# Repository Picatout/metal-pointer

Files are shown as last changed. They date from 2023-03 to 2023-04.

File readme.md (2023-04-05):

# Nail metal detector 

This is a mail metal detector using a NUCLEO-8S207K8 module with [stm8_tbi](https://github.com/picatout/stm8_tbi).

The Tiny BASIC application  [metal-detector.bas](metal-detector.bas)

* [revision notes](#revisions) 

##  Final choice for circuit 

At the end I chose the **L-R** time constant variation circuit for the stability and a coil with ferrite for sensivity . See [bare-metal/readme.md](bare-metal/readme.md) for more information. 

## Schematic, version 2

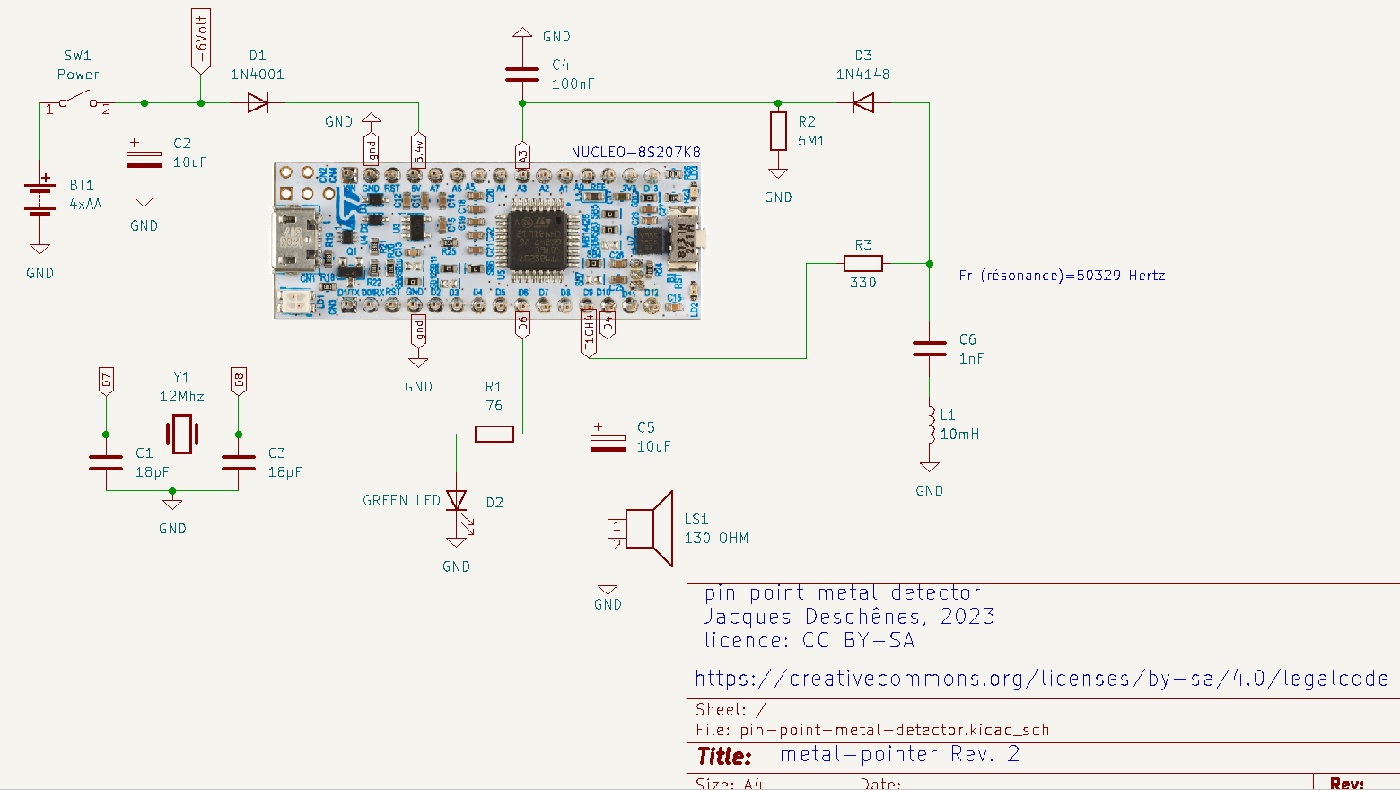
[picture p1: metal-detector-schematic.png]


## prototype, version 1



## Working principle

**C6** and **L1** form a series resonance circuit which frequency is 
Fr=1/(2 * 3.1416 * sqrt(1e-9*10e-3))=50329 Hertz 

**PWM** Channel 4 is used to generate a frequency at or near resonnance. This signal is injected in C4-L1 through R3. At resonant frequency voltage at junction R3-C4 is minimum.
This voltage is rectified by diode **D3** and measured by the analog/digital converter on channel **A3**. 

When a metal object come close to **L1** it modify the inductance then **C6-L1** resonnance is no more at PWM frequency and the voltage increase at **R3-C6** junction. An alarm is then sounded for 10msec and the GREEN LED **D2** light up. 

12Mhz crystal **Y1** is added to the NUCLEO-S207K8 board to increase frequency stability.

**L1** is a commercial inductor wound on a ferrite core. 

## Revisions 

### 2023-03-05 

Final assembly see [bare-metal/readme.md](bare-metal/readme.md)

### version 7 (STM8103F3M) final circuit 

* Final source code:  [nail-finder.v6.asm](bare-metal/nail-finder.v6.asm)

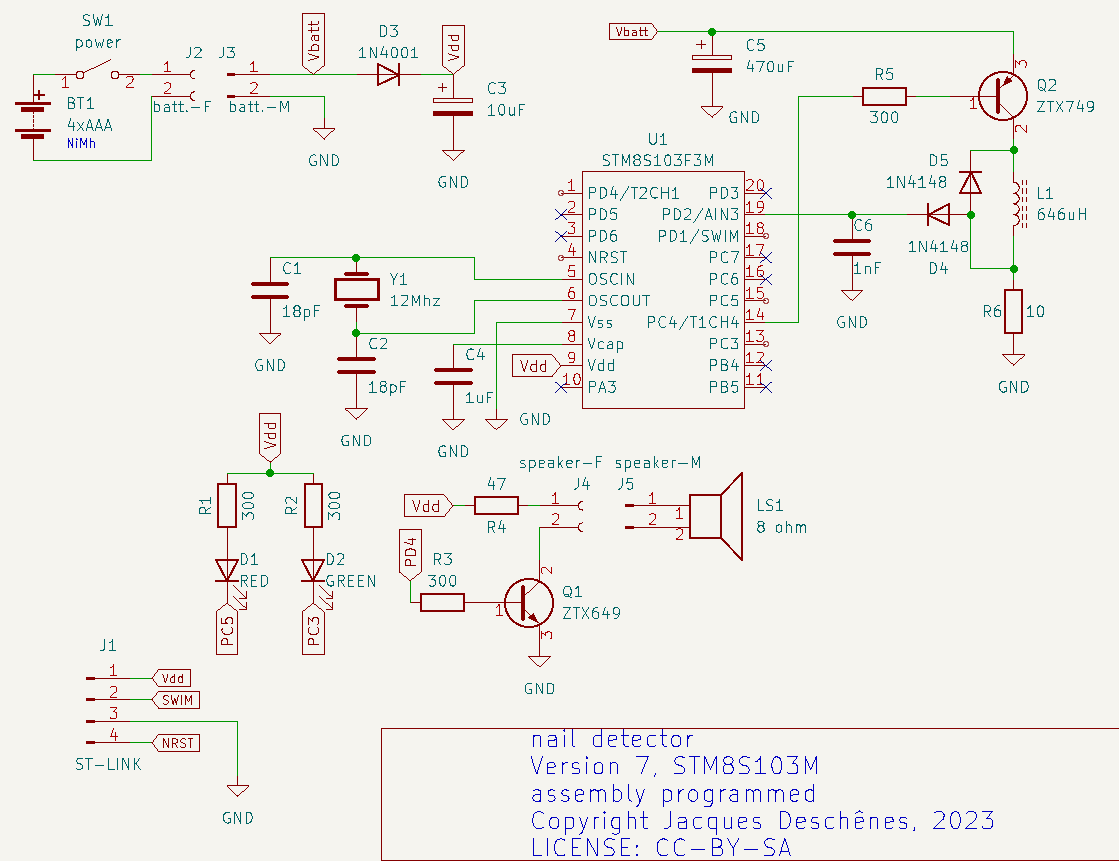
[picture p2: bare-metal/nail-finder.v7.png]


### version 6 (STM8S103F3M) assembly coded. 

Best result up to now. see [bare-metal/readme.md](bare-metal/readme.md) for detail.

### version 3 (STM8S105KBB6) R2

* Added double tonalities to alarm to distinguish between *going closer* and *going further*. For steel going closer generate higher pitch and going further generate lower pitch. For nickel it is the opposite.

* Added a buffer transistor to speaker as the sounding alarm was dropping *Vdda* affecting sample reading.

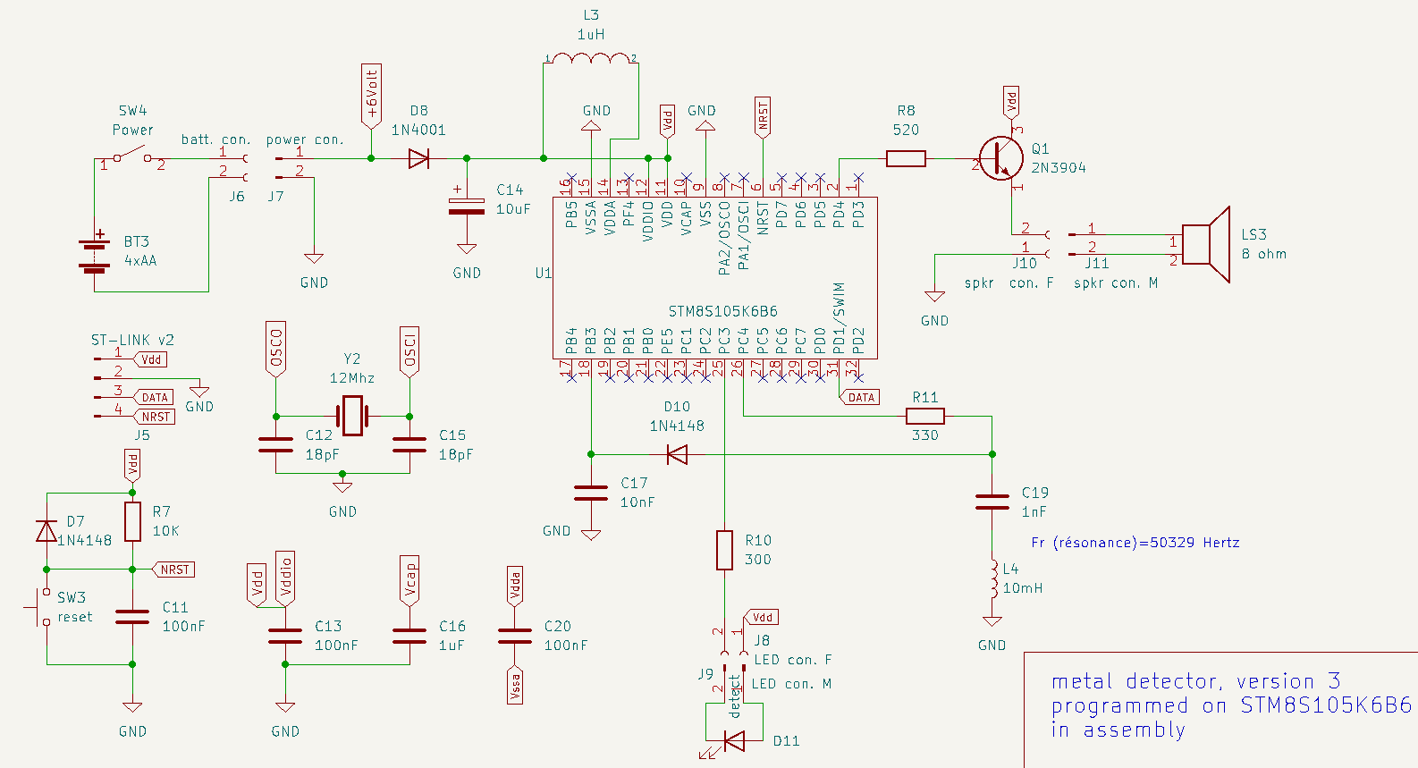
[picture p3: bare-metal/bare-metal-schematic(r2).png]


### version 3  (STM8S105KBB6) R1

Bare metal programming in assembly on STM8S105K6B6. 

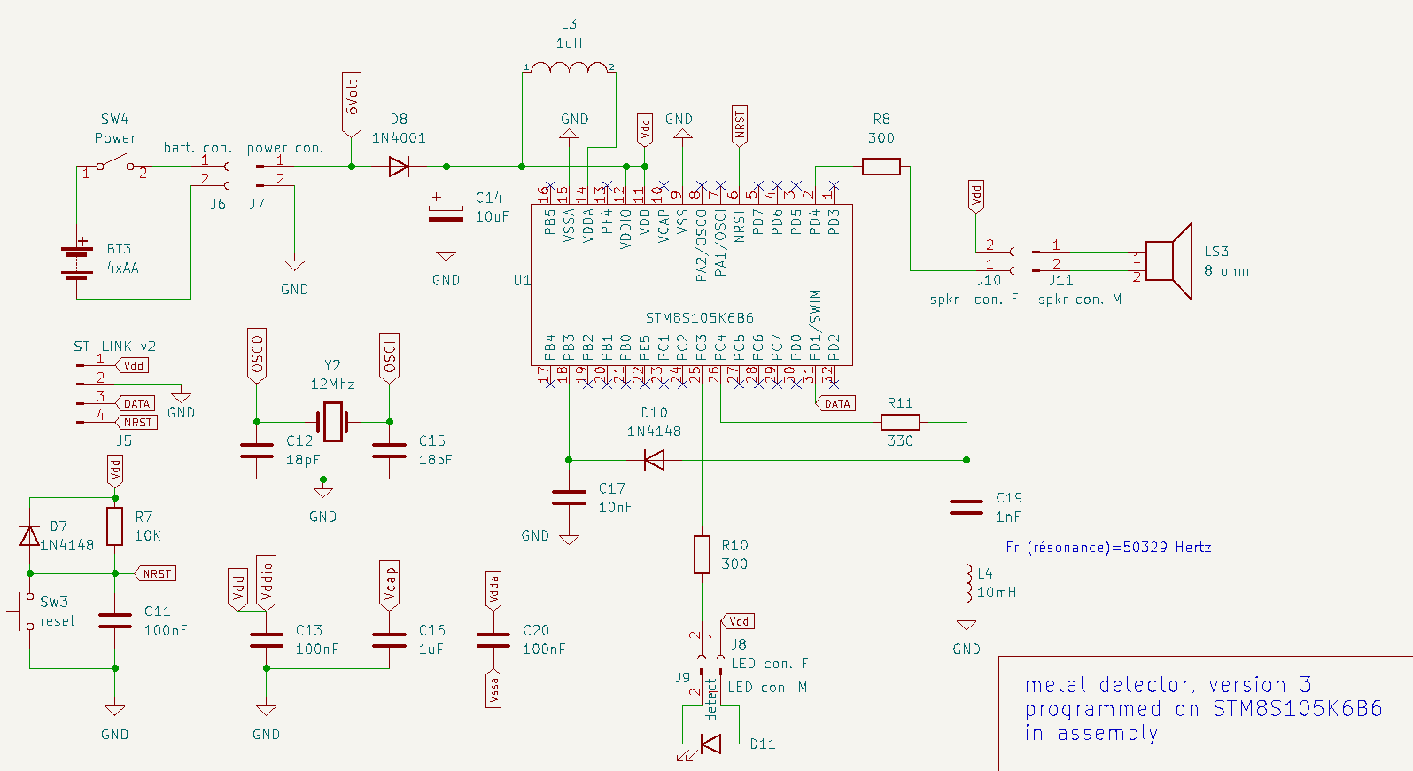
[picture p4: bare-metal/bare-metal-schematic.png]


### Version 2 

* Sheet **version 2** in KiCAD schematic. In this version the external 12Mhz crystal is discarded. The **SB5** bride on NUCLEO board is closed which bring 8Mhz **TMCO** signal to STM8 PA1 pin.
This version of metal detector use new command **CLK_HSE** from last version of [STM8 Tiny BASIC](https://github.com/picatout/stm8_tbi).

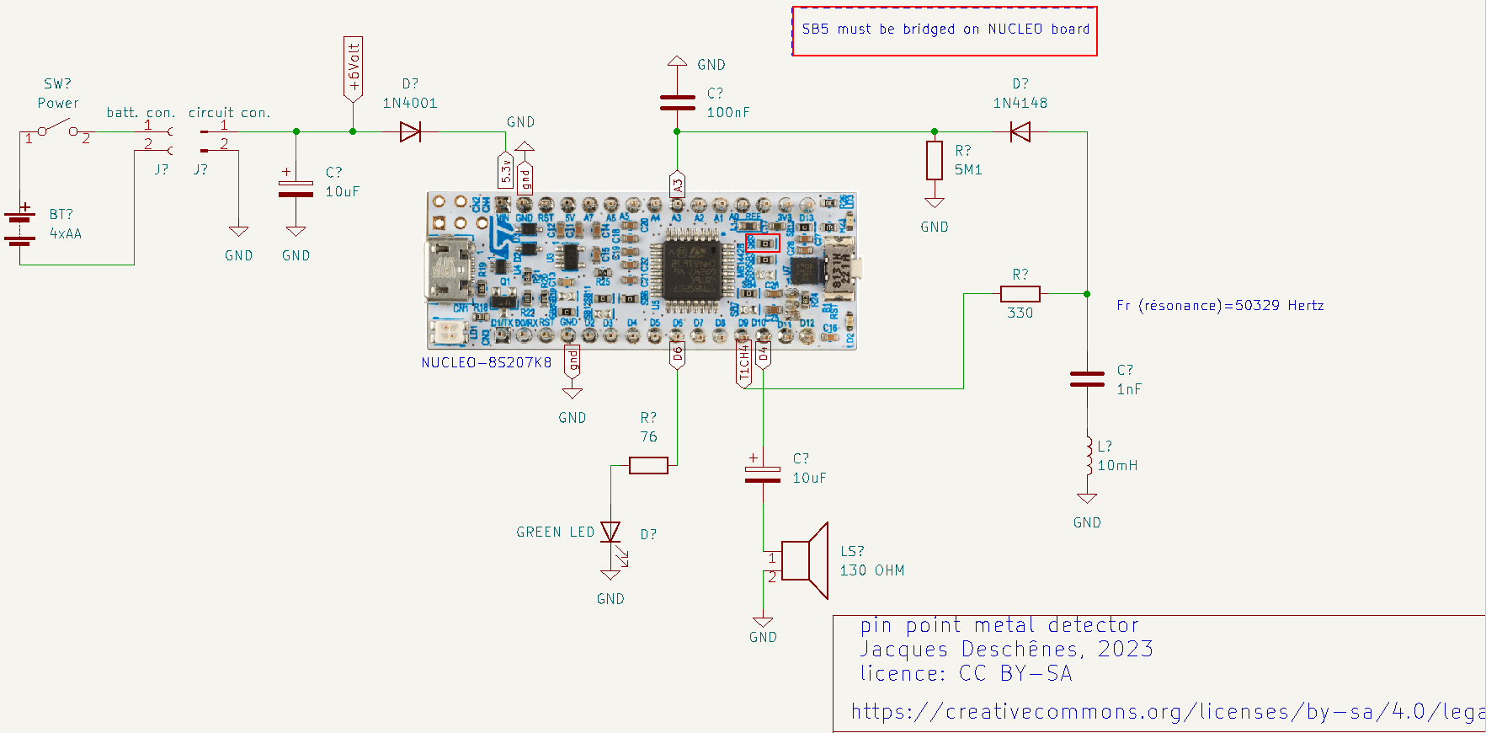
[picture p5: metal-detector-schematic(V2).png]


### Revision 3 

* I had wrongly connected cathode of **D1** to **CN4:4 (Vin)**  instead of **CN4:1 (5V)**.    

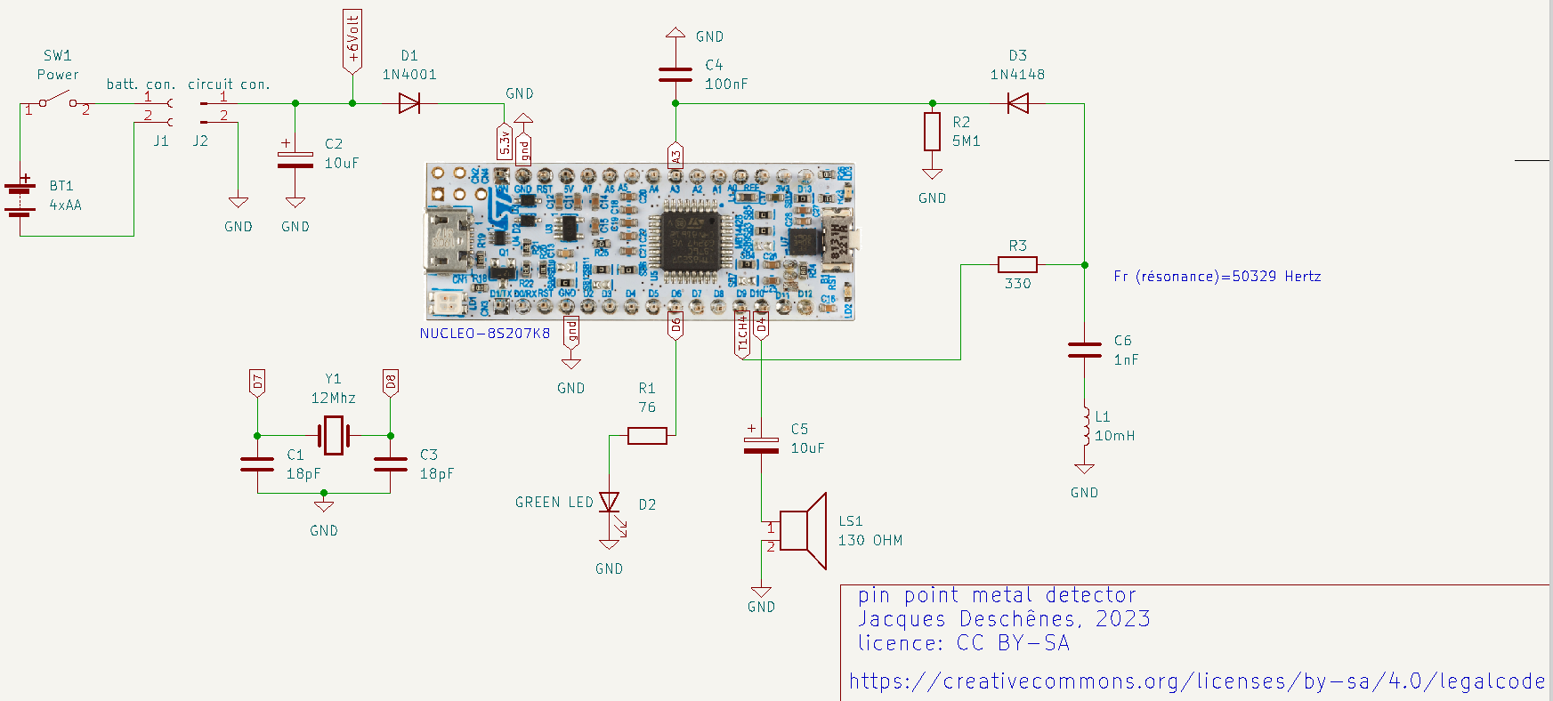
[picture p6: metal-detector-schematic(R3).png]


[short video demo](https://youtube.com/shorts/o5VKi-kE5qI?feature=share) 

### Revision 2 

*  Modified schematic and [metal-detector.bas](metal-detector.bas) to improve sensitivity.

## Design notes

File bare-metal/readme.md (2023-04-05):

# Version 7 
### 2023-04-05

Last circuit modification, new coil to increase detection area. I replaced the rod wounded coil by half cylindral wounded coil. The inductance is a little higher 646µH instead of 622µH. 
For this coil I used half of cable ferrite as core. 

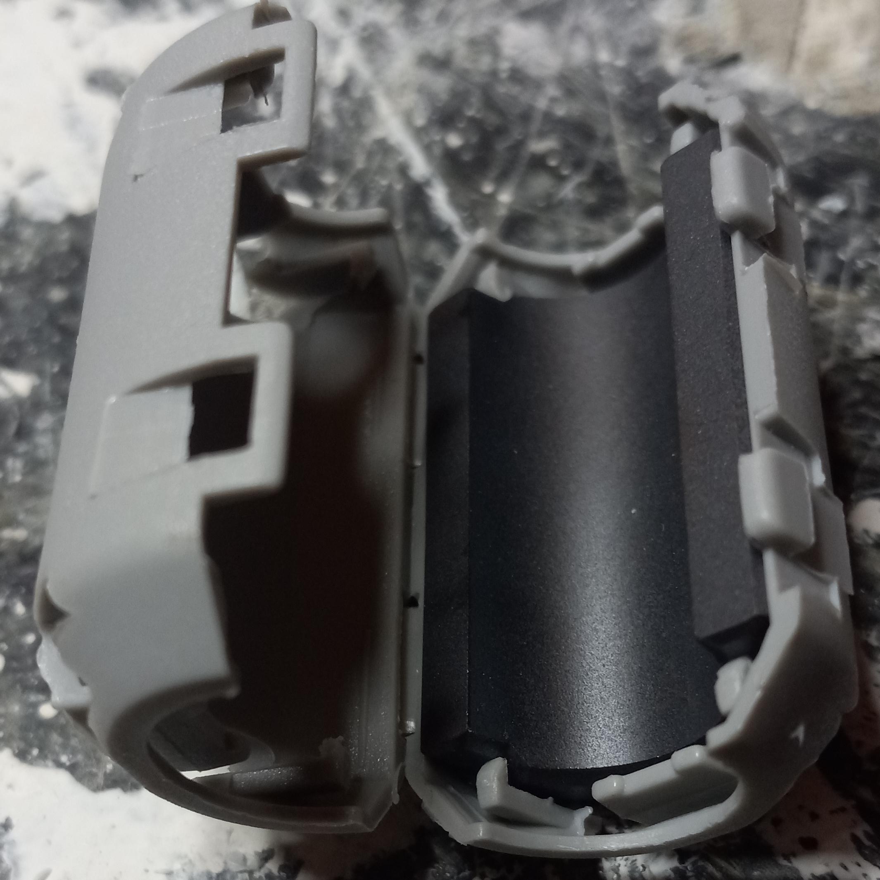
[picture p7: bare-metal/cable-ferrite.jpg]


I removed one half from plastic shell to use as core. Using 30 AWG enameled wire . With 2 layers of this wire I measured 644µH. 

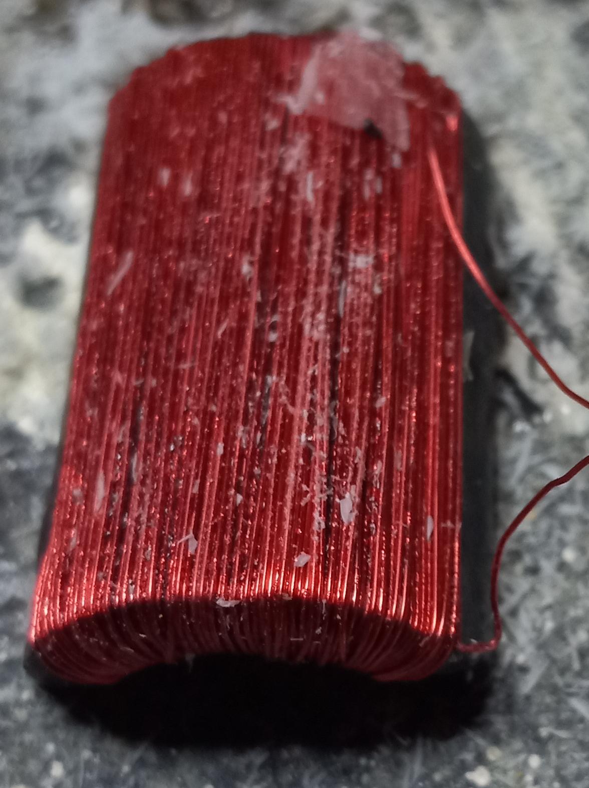
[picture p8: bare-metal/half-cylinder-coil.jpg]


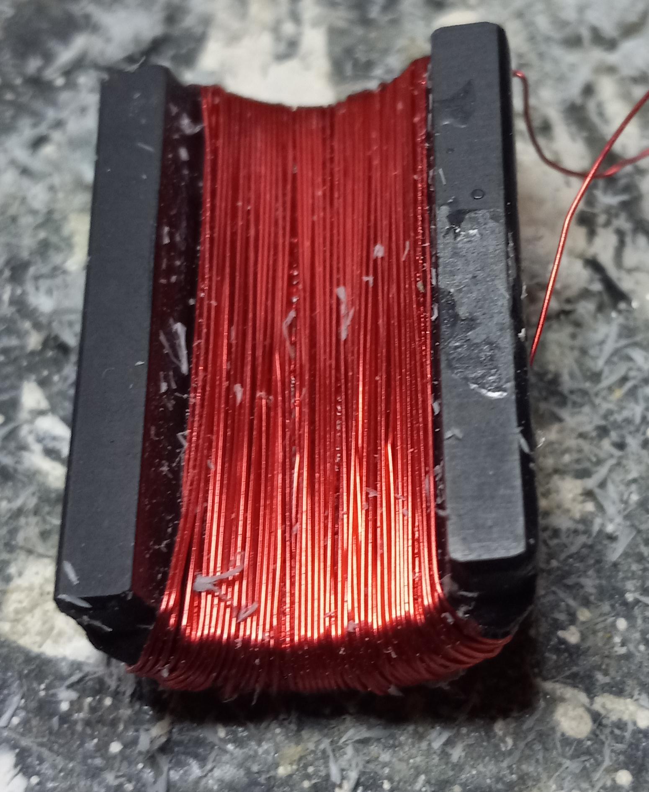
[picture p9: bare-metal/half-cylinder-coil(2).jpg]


I cutted 2 slot at the bottom of the box to push the coil edges flush to it an used epoxy glue to hold in place.

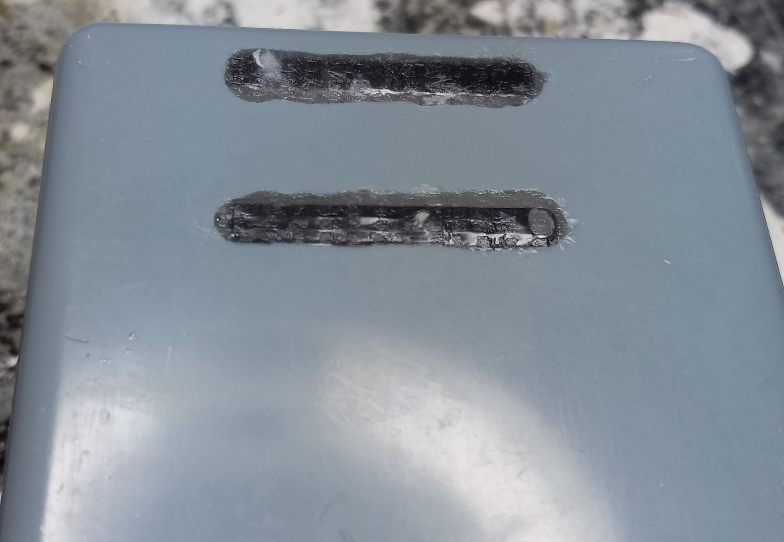
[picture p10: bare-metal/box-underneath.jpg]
box-underneath


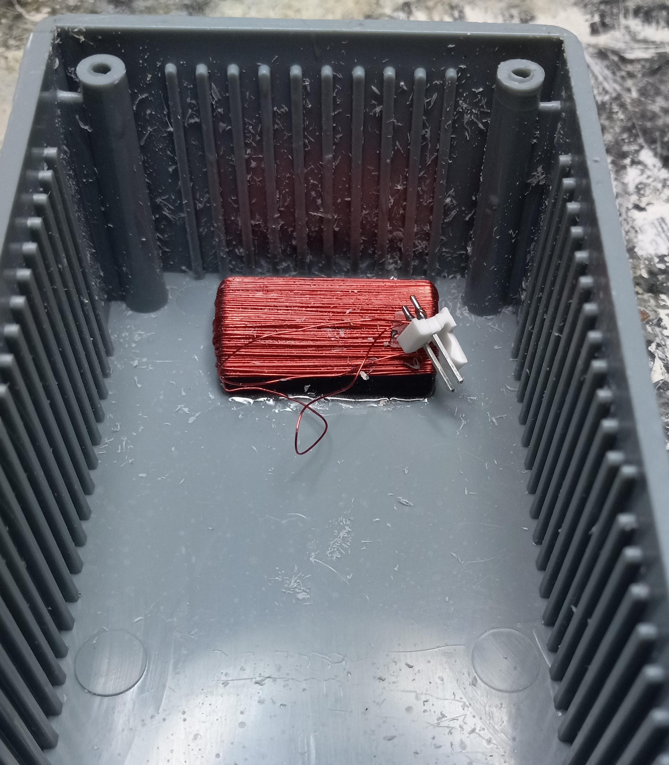
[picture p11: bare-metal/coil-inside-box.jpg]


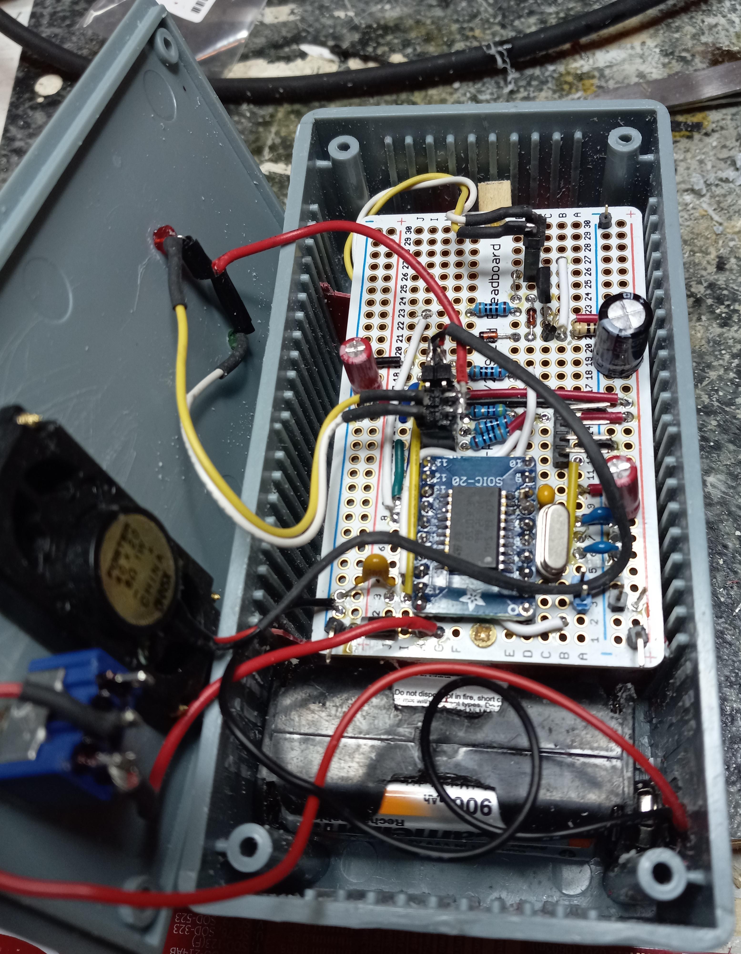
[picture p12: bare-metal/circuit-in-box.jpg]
circuit in box


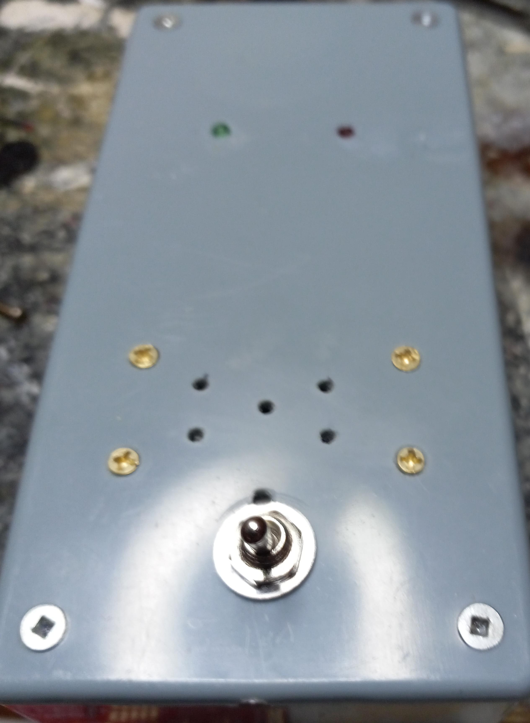
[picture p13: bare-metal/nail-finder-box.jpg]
nail finder box


Demo video [here](https://youtu.be/uCpbacAko6Q).

## 2023-03-29 

* Improved sensivity. 

* Tried a new coil on rod ferrite. [rod datasheet](ferrite-rod-4077484611.pdf).

* Updated firmware [nail-finder.v6.asm](nail-finder.v6.asm).

After many different circuits test I decided for the following circuit giving the best result.
* Use **STM8S103F3M**  SOIC-20 format  MCU. 
* Coded in assembly [nail-finder.v6.asm](nail-finder.v6.asm).



I'm waiting for an ordered ferrite to test new coil idea before doing a final assembly.

### How it works 

The working principle is different from previous version. Instead on measuring difference in voltage induced by varying resonnance frequency.  It measure variations in voltage induce by variation in time constant of **L-R** circuit.   

A short pulse is sent to **L1-R4** circuit. Voltage at **R4** increase exponentially in relation to Time constant **T=L/R**.  Metal nearby **L1** change its inductance hence the time constant variation. The duration of pulse is chosen to be short enough that the voltage at **R1** never reach Vdd (current through L1-R1 never reach its maximum). Hence the voltage at end of pulse depend on time constant.

This circuit prove to be very reliable in stability and the **L1** ferrite core improve sensitivity. 

# version 6 

* best result up to date. 
    * improved sensivity 
    * very few false alarms. 

[new software](nail-finder.v6.asm) and new circuit. 

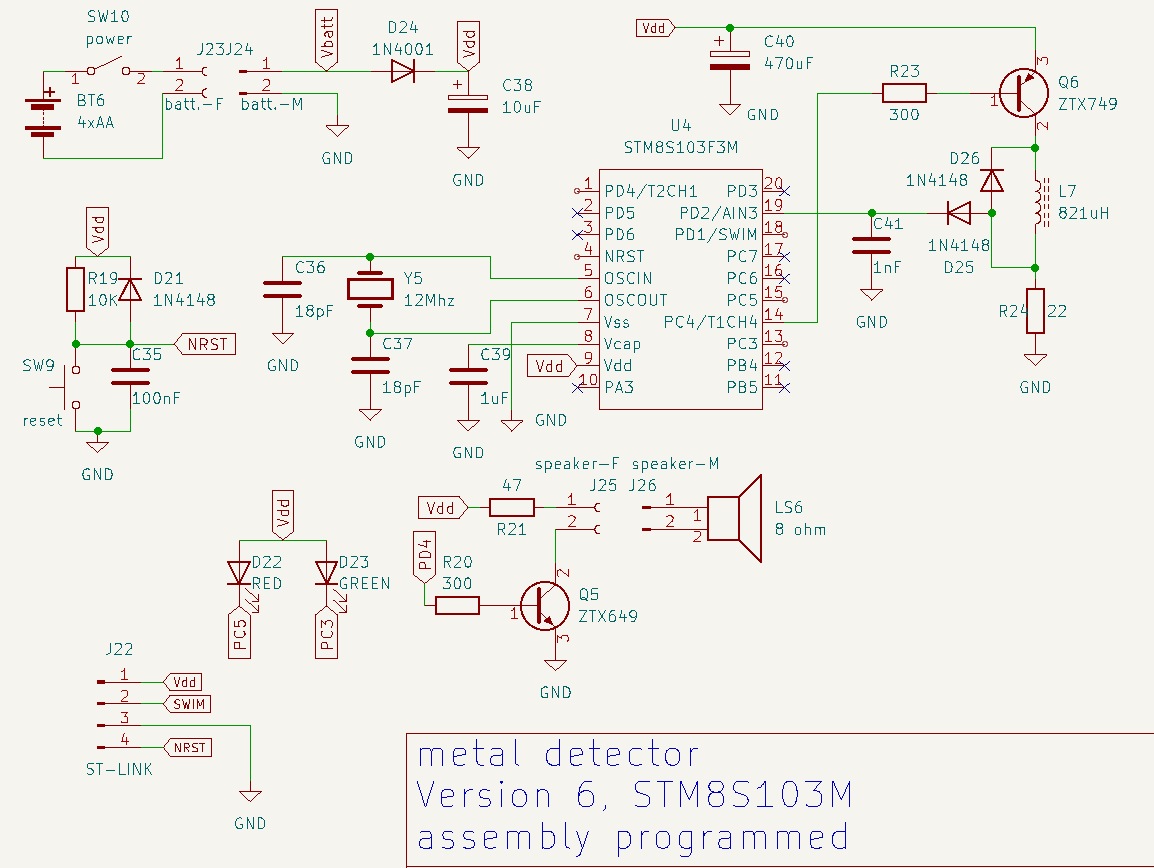
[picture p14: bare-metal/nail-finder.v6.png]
new circuit
 

The inductor **L7** is 26 AWG enamel wire wounded on a ferrite rod recuperated from old radio. 
The rod is 7mm diameter. The winding is 2 layers 3 cm in length. The measure inductance is 821uH.

# version 4 

### 2023-03-22 

La configuration tested. Use a coil on ferrite rod.

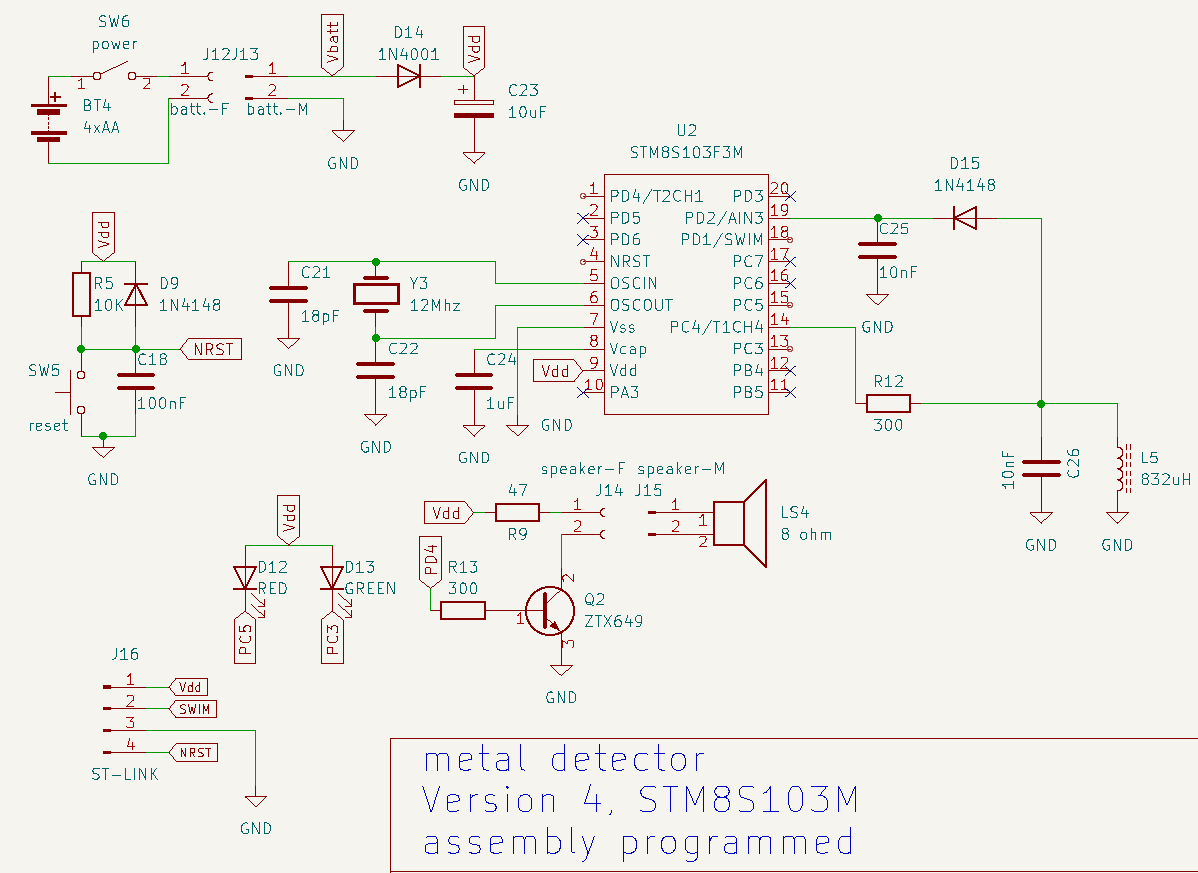
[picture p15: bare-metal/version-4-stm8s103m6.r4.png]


This version is programmed on **STM8S103F3M" in assembly. Still in development. 

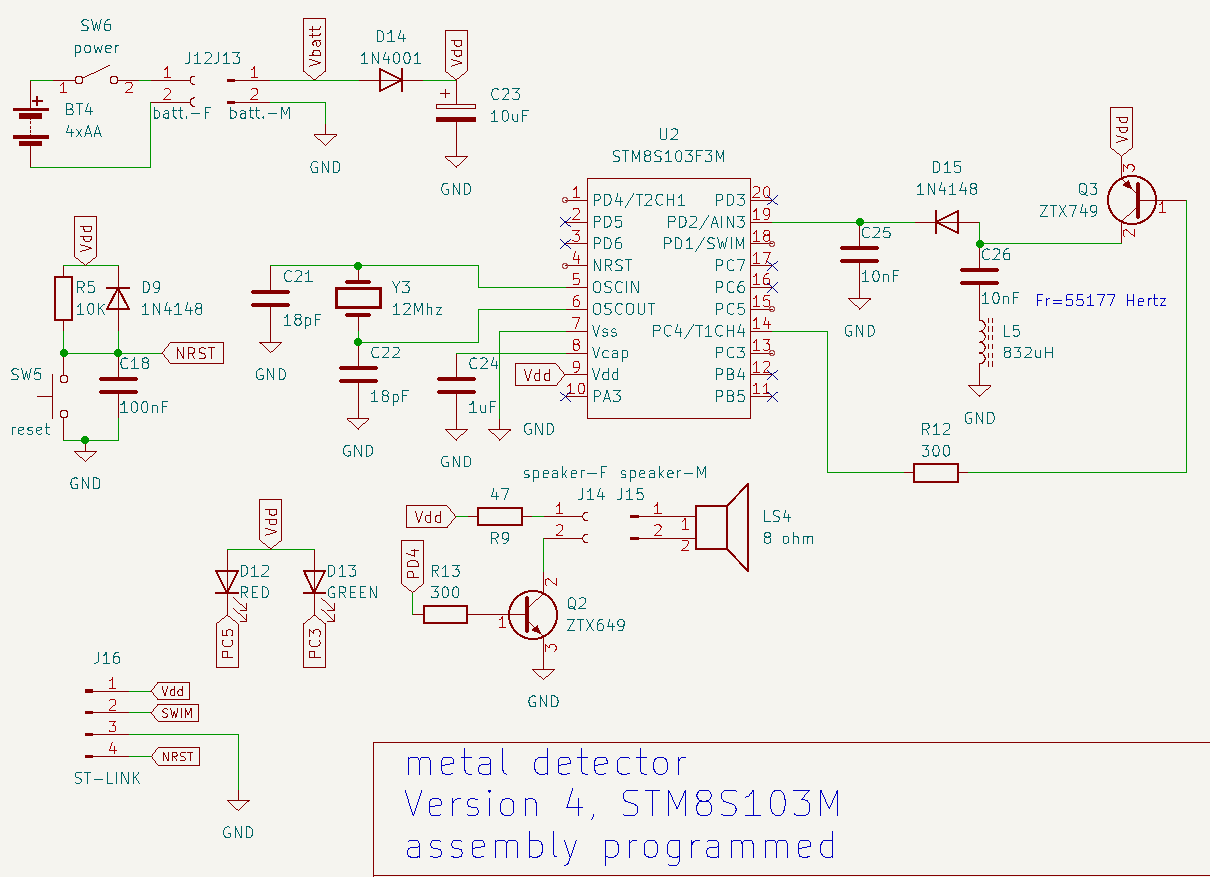
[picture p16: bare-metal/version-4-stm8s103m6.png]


# Version 3 

This version in programmed on **STM8S105K6B6** in assembly.



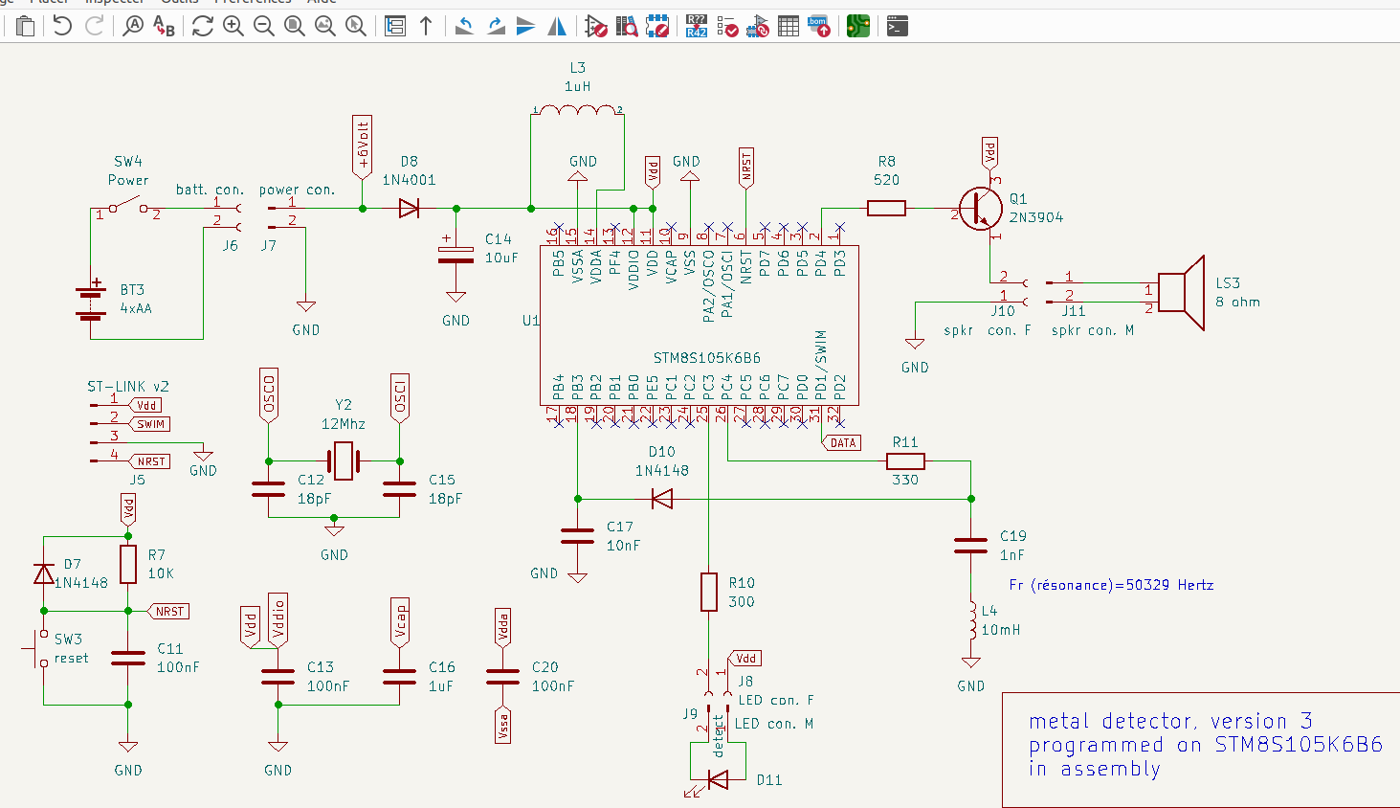
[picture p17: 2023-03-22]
bare-metal/metal-detector-schematic(R3).png

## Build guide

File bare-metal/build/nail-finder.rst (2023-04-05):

ASxxxx Assembler V02.00 + NoICE + SDCC mods  (STMicroelectronics STM8), page 1.
Hexadecimal [24-Bits]

                                      1 ;--------------------
                                      2 ; bare metal version 
                                      3 ; on STM8S103f3m 
                                      4 ; 
                                      5 ; last change: 2023-03-24
                                      6 ;--------------------
                                      7 
                                      8     .module METAL_POINTER 
                                      9 

ASxxxx Assembler V02.00 + NoICE + SDCC mods  (STMicroelectronics STM8), page 2.
Hexadecimal [24-Bits]

                                     10     .include "inc/macros.inc" 
                                      1 ;;;;;;;;;;;;;;;;;;;;;;;;;;;;;;;;;;;;;;;;;;;;;;;;;;;;;;;;;;;;;;;;;;;;;;;;;;;;;;;;
                                      2 ;; Copyright Jacques Deschênes 2019,2020,2021 
                                      3 ;; This file is part of stm32_eforth  
                                      4 ;;
                                      5 ;;     stm8_eforth is free software: you can redistribute it and/or modify
                                      6 ;;     it under the terms of the GNU General Public License as published by
                                      7 ;;     the Free Software Foundation, either version 3 of the License, or
                                      8 ;;     (at your option) any later version.
                                      9 ;;
                                     10 ;;     stm32_eforth is distributed in the hope that it will be useful,
                                     11 ;;     but WITHOUT ANY WARRANTY;; without even the implied warranty of
                                     12 ;;     MERCHANTABILITY or FITNESS FOR A PARTICULAR PURPOSE.  See the
                                     13 ;;     GNU General Public License for more details.
                                     14 ;;
                                     15 ;;     You should have received a copy of the GNU General Public License
                                     16 ;;     along with stm32_eforth.  If not, see <http:;;www.gnu.org/licenses/>.
                                     17 ;;;;
                                     18 ;;;;;;;;;;;;;;;;;;;;;;;;;;;;;;;;;;;;;;;;;;;;;;;;;;;;;;;;;;;;;;;;;;;;;;;;;;;;;;;;
                                     19 
                                     20 ;--------------------------------------
                                     21 ;   console Input/Output module
                                     22 ;   DATE: 2019-12-11
                                     23 ;    
                                     24 ;   General usage macros.   
                                     25 ;
                                     26 ;--------------------------------------
                                     27     
                                     28     ; reserve space on rstack
                                     29     ; for local variabls
                                     30     .macro _VARS n 
                                     31     sub sp,#n 
                                     32     .endm 
                                     33     
                                     34     ; discard space reserved 
                                     35     ; for local vars on rstack 
                                     36     .macro _DROP_VARS n 
                                     37     addw sp,#n
                                     38     .endm 
                                     39 
                                     40     ; declare ARG_OFS for arguments 
                                     41     ; displacement on stack. This 
                                     42     ; value depend on local variables 
                                     43     ; size.
                                     44     .macro _argofs n 
                                     45     ARG_OFS=2+n 
                                     46     .endm 
                                     47 
                                     48     ; declare a function argument 
                                     49     ; position relative to stack pointer 
                                     50     ; _argofs must be called before it.
                                     51     .macro _arg name ofs 
                                     52     name=ARG_OFS+ofs 
                                     53     .endm 
                                     54 

ASxxxx Assembler V02.00 + NoICE + SDCC mods  (STMicroelectronics STM8), page 3.
Hexadecimal [24-Bits]

                                     55     ; macro to create dictionary header record
                                     56     .macro _HEADER label,len,name 
                                     57         .word LINK 
                                     58         LINK=.
                                     59         .byte len  
                                     60         .ascii name
                                     61         label:
                                     62     .endm 
                                     63 
                                     64     ; runtime literal 
                                     65     .macro _DOLIT value 
                                     66     CALL DOLIT 
                                     67     .word value 
                                     68     .endm 
                                     69 
                                     70     ; branch if TOS<>0
                                     71     ; TBRANCH 
                                     72     .macro _TBRAN target 
                                     73     CALL TBRAN 
                                     74     .word target 
                                     75     .endm 
                                     76     
                                     77     ; branch if TOS==0 
                                     78     ; 0BRANCH 
                                     79     .macro _QBRAN target 
                                     80     CALL QBRAN
                                     81     .word target
                                     82     .endm 
                                     83 
                                     84     ; uncondittionnal BRANCH 
                                     85     .macro _BRAN target 
                                     86     JRA target  
                                     87     .endm 
                                     88 
                                     89     ; run time NEXT 
                                     90     .macro _DONXT target 
                                     91     CALL DONXT 
                                     92     .word target 
                                     93     .endm 
                                     94 
                                     95     ; drop TOS 
                                     96     .macro _DROP 
                                     97     ADDW X,#CELLL  
                                     98     .endm 
                                     99   
                                    100    ; drop a double 
                                    101    .macro _DDROP 
                                    102    ADDW X,#2*CELLL 
                                    103    .endm 
                                    104 
                                    105     ; drop n CELLS
                                    106     .macro _DROPN n 
                                    107     ADDW X,#n*CELLL 
                                    108     .endm 
                                    109 

ASxxxx Assembler V02.00 + NoICE + SDCC mods  (STMicroelectronics STM8), page 4.
Hexadecimal [24-Bits]

                                    110    ; drop from rstack 
                                    111    .macro _RDROP 
                                    112    ADDW SP,#CELLL
                                    113    .endm 
                                    114 
                                    115    ; drop double from rstack
                                    116    .macro _DRDROP
                                    117    ADDW SP,#2*CELLL 
                                    118    .endm 
                                    119 
                                    120    ; test point, print character 
                                    121    ; and stack contain
                                    122    .macro _TP c 
                                    123    .if DEBUG 
                                    124    LD A,#c 
                                    125    CALL putc
                                    126    CALL DOTS 
                                    127    .endif  
                                    128    .endm 

ASxxxx Assembler V02.00 + NoICE + SDCC mods  (STMicroelectronics STM8), page 5.
Hexadecimal [24-Bits]

                                     11     .include "inc/stm8s103f3.inc"
                                      1 ;;;;;;;;;;;;;;;;;;;;;;;;;;;;;;;;;;;;;;;;;;;;;;;;;;;;;;;;;;;;;;;;;;;;;;;;;;;;;;;;
                                      2 ;; Copyright Jacques Deschênes 2019,2020,2021 
                                      3 ;; This file is part of stm32_eforth  
                                      4 ;;
                                      5 ;;     stm8_eforth is free software: you can redistribute it and/or modify
                                      6 ;;     it under the terms of the GNU General Public License as published by
                                      7 ;;     the Free Software Foundation, either version 3 of the License, or
                                      8 ;;     (at your option) any later version.
                                      9 ;;
                                     10 ;;     stm32_eforth is distributed in the hope that it will be useful,
                                     11 ;;     but WITHOUT ANY WARRANTY;; without even the implied warranty of
                                     12 ;;     MERCHANTABILITY or FITNESS FOR A PARTICULAR PURPOSE.  See the
                                     13 ;;     GNU General Public License for more details.
                                     14 ;;
                                     15 ;;     You should have received a copy of the GNU General Public License
                                     16 ;;     along with stm32_eforth.  If not, see <http:;;www.gnu.org/licenses/>.
                                     17 ;;;;
                                     18 ;;;;;;;;;;;;;;;;;;;;;;;;;;;;;;;;;;;;;;;;;;;;;;;;;;;;;;;;;;;;;;;;;;;;;;;;;;;;;;;;
                                     19 
                                     20 ;;;;;;;;;;;;;;;;;;;;;;;;;;;;;;;;;;;
                                     21 ; 2019/04/26
                                     22 ; STM8S105x4/6 µC registers map
                                     23 ;;;;;;;;;;;;;;;;;;;;;;;;;;;;;;;;;;;;
                                     24 	.module stm8s105c6
                                     25 	
                                     26 ;;;;;;;;;;
                                     27 ; bit mask
                                     28 ;;;;;;;;;;
                           000000    29  BIT0 = (0)
                           000001    30  BIT1 = (1)
                           000002    31  BIT2 = (2)
                           000003    32  BIT3 = (3)
                           000004    33  BIT4 = (4)
                           000005    34  BIT5 = (5)
                           000006    35  BIT6 = (6)
                           000007    36  BIT7 = (7)
                                     37 
                                     38 ; controller memory regions
                           000400    39 RAM_SIZE = (1024) 
                           000280    40 EEPROM_SIZE = (640) 
                           002000    41 FLASH_SIZE = (8192)
                                     42 
                           000000    43  RAM_BASE = (0)
                           0003FF    44  RAM_END = (RAM_BASE+RAM_SIZE-1)
                           004000    45  EEPROM_BASE = (0x4000)
                           00427F    46  EEPROM_END = (EEPROM_BASE+EEPROM_SIZE-1)
                           005000    47  SFR_BASE = (0x5000)
                           0057FF    48  SFR_END = (0x57FF)
                           008000    49  FLASH_BASE = (0x8000)
                           004800    50  OPTION_BASE = (0x4800)
                           00480A    51  OPTION_END = (0x480A)
                           004865    52  DEVID_BASE = (0x4865)
                           004870    53  DEVID_END = (0x4870)
                           000040    54  BLOCK_SIZE = 64 ; flash|eeprom block size

ASxxxx Assembler V02.00 + NoICE + SDCC mods  (STMicroelectronics STM8), page 6.
Hexadecimal [24-Bits]

                           004000    55 GPIO_BASE = (0x4000)
                           0057FF    56 GPIO_END = (0x57ff)
                                     57 
                                     58 ; options bytes
                                     59 ; this one can be programmed only from SWIM  (ICP)
                           004800    60  OPT0  = (0x4800)
                                     61 ; these can be programmed at runtime (IAP)
                           004801    62  OPT1  = (0x4801)
                           004802    63  NOPT1  = (0x4802)
                           004803    64  OPT2  = (0x4803)
                           004804    65  NOPT2  = (0x4804)
                           004805    66  OPT3  = (0x4805)
                           004806    67  NOPT3  = (0x4806)
                           004807    68  OPT4  = (0x4807)
                           004808    69  NOPT4  = (0x4808)
                           004809    70  OPT5  = (0x4809)
                           00480A    71  NOPT5  = (0x480A)
                                     72 ; option registers usage
                                     73 ; read out protection, value 0xAA enable ROP
                           004800    74  ROP = OPT0  
                                     75 ; user boot code, {0..0x3e} 512 bytes row
                           004801    76  UBC = OPT1
                           004802    77  NUBC = NOPT1
                                     78 ; alternate function register
                           004803    79  AFR = OPT2
                           004804    80  NAFR = NOPT2
                                     81 ; miscelinous options
                           004805    82  MISCOPT = OPT3
                           004806    83  NMISCOPT = NOPT3
                                     84 ; clock options
                           004807    85  CLKOPT = OPT4
                           004808    86  NCLKOPT = NOPT4
                                     87 ; HSE clock startup delay
                           004809    88  HSECNT = OPT5
                           00480A    89  NHSECNT = NOPT5
                                     90 
                                     91 ; MISCOPT bits
                           000004    92   MISCOPT_HSITRIM =  BIT4
                           000003    93   MISCOPT_LSIEN   =  BIT3
                           000002    94   MISCOPT_IWDG_HW =  BIT2
                           000001    95   MISCOPT_WWDG_HW =  BIT1
                           000000    96   MISCOPT_WWDG_HALT = BIT0
                                     97 ; NMISCOPT bits
                           FFFFFFFB    98   NMISCOPT_NHSITRIM  = ~BIT4
                           FFFFFFFC    99   NMISCOPT_NLSIEN    = ~BIT3
                           FFFFFFFD   100   NMISCOPT_NIWDG_HW  = ~BIT2
                           FFFFFFFE   101   NMISCOPT_NWWDG_HW  = ~BIT1
                           FFFFFFFF   102   NMISCOPT_NWWDG_HALT = ~BIT0
                                    103 ; CLKOPT bits
                           000003   104  CLKOPT_EXT_CLK  = BIT3
                           000002   105  CLKOPT_CKAWUSEL = BIT2
                           000001   106  CLKOPT_PRS_C1   = BIT1
                           000000   107  CLKOPT_PRS_C0   = BIT0
                                    108 
                                    109 ; AFR option, remapable functions

ASxxxx Assembler V02.00 + NoICE + SDCC mods  (STMicroelectronics STM8), page 7.
Hexadecimal [24-Bits]

                           000007   110  AFR7 = BIT7 ;Port C3 = TIM1_CH1N; port C4 = TIM1_CH2N.
                           000006   111  AFR6 = BIT6 ;reserved  
                           000005   112  AFR5 = BIT5 ;reserved 
                           000004   113  AFR4 = BIT4 ;Port B4 = ADC1_ETR; port B5 =TIM1_BKIN
                           000003   114  AFR3 = BIT3 ;Port C3 = TLI
                           000002   115  AFR2 = BIT2 ;reserved
                           000001   116  AFR1 = BIT1 ;Port A3 = SPI_NSS; port D2 =TIM2_CH3
                           000000   117  AFR0 = BIT0 ;Port C5 = TIM2_CH1; port C6 =TIM1_CH1; port C7 = TIM1_CH2
                                    118 
                                    119 ; device ID = (read only)
                           0048CD   120  DEVID_XL  = (0x48CD)
                           0048CE   121  DEVID_XH  = (0x48CE)
                           0048CF   122  DEVID_YL  = (0x48CF)
                           0048D0   123  DEVID_YH  = (0x48D0)
                           0048D1   124  DEVID_WAF  = (0x48D1)
                           0048D2   125  DEVID_LOT0  = (0x48D2)
                           0048D3   126  DEVID_LOT1  = (0x48D3)
                           0048D4   127  DEVID_LOT2  = (0x48D4)
                           0048D5   128  DEVID_LOT3  = (0x48D5)
                           0048D6   129  DEVID_LOT4  = (0x48D6)
                           0048D7   130  DEVID_LOT5  = (0x48D7)
                           0048D8   131  DEVID_LOT6  = (0x48D8)
                                    132 
                                    133 
                                    134 ; port bit
                           000000   135  PIN0 = (0)
                           000001   136  PIN1 = (1)
                           000002   137  PIN2 = (2)
                           000003   138  PIN3 = (3)
                           000004   139  PIN4 = (4)
                           000005   140  PIN5 = (5)
                           000006   141  PIN6 = (6)
                           000007   142  PIN7 = (7)
                                    143 
                           005000   144 GPIO_BASE = (0x5000)
                           000005   145 GPIO_SIZE = (5)
                                    146 ; PORTS SFR OFFSET
                           000000   147 PA = 0
                           000005   148 PB = 5
                           00000A   149 PC = 10
                           00000F   150 PD = 15
                           000014   151 PE = 20
                           000019   152 PF = 25
                                    153 
                                    154 ; GPIO
                           005000   155  PA_ODR  = (0x5000)
                           005001   156  PA_IDR  = (0x5001)
                           005002   157  PA_DDR  = (0x5002)
                           005003   158  PA_CR1  = (0x5003)
                           005004   159  PA_CR2  = (0x5004)
                                    160 
                           005005   161  PB_ODR  = (0x5005)
                           005006   162  PB_IDR  = (0x5006)
                           005007   163  PB_DDR  = (0x5007)
                           005008   164  PB_CR1  = (0x5008)

ASxxxx Assembler V02.00 + NoICE + SDCC mods  (STMicroelectronics STM8), page 8.
Hexadecimal [24-Bits]

                           005009   165  PB_CR2  = (0x5009)
                                    166 
                           00500A   167  PC_ODR  = (0x500A)
                           00500B   168  PC_IDR  = (0x500B)
                           00500C   169  PC_DDR  = (0x500C)
                           00500D   170  PC_CR1  = (0x500D)
                           00500E   171  PC_CR2  = (0x500E)
                                    172 
                           00500F   173  PD_ODR  = (0x500F)
                           005010   174  PD_IDR  = (0x5010)
                           005011   175  PD_DDR  = (0x5011)
                           005012   176  PD_CR1  = (0x5012)
                           005013   177  PD_CR2  = (0x5013)
                                    178 
                           005014   179  PE_ODR  = (0x5014)
                           005015   180  PE_IDR  = (0x5015)
                           005016   181  PE_DDR  = (0x5016)
                           005017   182  PE_CR1  = (0x5017)
                           005018   183  PE_CR2  = (0x5018)
                                    184 
                           005019   185  PF_ODR  = (0x5019)
                           00501A   186  PF_IDR  = (0x501A)
                           00501B   187  PF_DDR  = (0x501B)
                           00501C   188  PF_CR1  = (0x501C)
                           00501D   189  PF_CR2  = (0x501D)
                                    190 
                                    191  ; input modes CR1
                           000000   192  INPUT_FLOAT = (0)
                           000001   193  INPUT_PULLUP = (1)
                                    194 ; output mode CR1
                           000000   195  OUTPUT_OD = (0)
                           000001   196  OUTPUT_PP = (1)
                                    197 ; input modes CR2
                           000000   198  INPUT_DI = (0)
                           000001   199  INPUT_EI = (1)
                                    200 ; output speed CR2
                           000000   201  OUTPUT_SLOW = (0)
                           000001   202  OUTPUT_FAST = (1)
                                    203 
                                    204 
                                    205 ; Flash
                           00505A   206  FLASH_CR1  = (0x505A)
                           00505B   207  FLASH_CR2  = (0x505B)
                           00505C   208  FLASH_NCR2  = (0x505C)
                           00505D   209  FLASH_FPR  = (0x505D)
                           00505E   210  FLASH_NFPR  = (0x505E)
                           00505F   211  FLASH_IAPSR  = (0x505F)
                           005062   212  FLASH_PUKR  = (0x5062)
                           005064   213  FLASH_DUKR  = (0x5064)
                                    214 ; data memory unlock keys
                           0000AE   215  FLASH_DUKR_KEY1 = (0xae)
                           000056   216  FLASH_DUKR_KEY2 = (0x56)
                                    217 ; flash memory unlock keys
                           000056   218  FLASH_PUKR_KEY1 = (0x56)
                           0000AE   219  FLASH_PUKR_KEY2 = (0xae)

ASxxxx Assembler V02.00 + NoICE + SDCC mods  (STMicroelectronics STM8), page 9.
Hexadecimal [24-Bits]

                                    220 ; FLASH_CR1 bits
                           000003   221  FLASH_CR1_HALT = BIT3
                           000002   222  FLASH_CR1_AHALT = BIT2
                           000001   223  FLASH_CR1_IE = BIT1
                           000000   224  FLASH_CR1_FIX = BIT0
                                    225 ; FLASH_CR2 bits
                           000007   226  FLASH_CR2_OPT = BIT7
                           000006   227  FLASH_CR2_WPRG = BIT6
                           000005   228  FLASH_CR2_ERASE = BIT5
                           000004   229  FLASH_CR2_FPRG = BIT4
                           000000   230  FLASH_CR2_PRG = BIT0
                                    231 ; FLASH_FPR bits
                           000005   232  FLASH_FPR_WPB5 = BIT5
                           000004   233  FLASH_FPR_WPB4 = BIT4
                           000003   234  FLASH_FPR_WPB3 = BIT3
                           000002   235  FLASH_FPR_WPB2 = BIT2
                           000001   236  FLASH_FPR_WPB1 = BIT1
                           000000   237  FLASH_FPR_WPB0 = BIT0
                                    238 ; FLASH_NFPR bits
                           000005   239  FLASH_NFPR_NWPB5 = BIT5
                           000004   240  FLASH_NFPR_NWPB4 = BIT4
                           000003   241  FLASH_NFPR_NWPB3 = BIT3
                           000002   242  FLASH_NFPR_NWPB2 = BIT2
                           000001   243  FLASH_NFPR_NWPB1 = BIT1
                           000000   244  FLASH_NFPR_NWPB0 = BIT0
                                    245 ; FLASH_IAPSR bits
                           000006   246  FLASH_IAPSR_HVOFF = BIT6
                           000003   247  FLASH_IAPSR_DUL = BIT3
                           000002   248  FLASH_IAPSR_EOP = BIT2
                           000001   249  FLASH_IAPSR_PUL = BIT1
                           000000   250  FLASH_IAPSR_WR_PG_DIS = BIT0
                                    251 
                                    252 ; Interrupt control
                           0050A0   253  EXTI_CR1  = (0x50A0)
                           0050A1   254  EXTI_CR2  = (0x50A1)
                                    255 
                                    256 ; Reset Status
                           0050B3   257  RST_SR  = (0x50B3)
                                    258 
                                    259 ; Clock Registers
                           0050C0   260  CLK_ICKR  = (0x50c0)
                           0050C1   261  CLK_ECKR  = (0x50c1)
                           0050C3   262  CLK_CMSR  = (0x50C3)
                           0050C4   263  CLK_SWR  = (0x50C4)
                           0050C5   264  CLK_SWCR  = (0x50C5)
                           0050C6   265  CLK_CKDIVR  = (0x50C6)
                           0050C7   266  CLK_PCKENR1  = (0x50C7)
                           0050C8   267  CLK_CSSR  = (0x50C8)
                           0050C9   268  CLK_CCOR  = (0x50C9)
                           0050CA   269  CLK_PCKENR2  = (0x50CA)
                           0050CC   270  CLK_HSITRIMR  = (0x50CC)
                           0050CD   271  CLK_SWIMCCR  = (0x50CD)
                                    272 
                                    273 ; Peripherals clock gating
                                    274 ; CLK_PCKENR1 

ASxxxx Assembler V02.00 + NoICE + SDCC mods  (STMicroelectronics STM8), page 10.
Hexadecimal [24-Bits]

                           000007   275  CLK_PCKENR1_TIM1 = (7)
                           000005   276  CLK_PCKENR1_TIM2 = (5)
                           000004   277  CLK_PCKENR1_TIM4 = (4)
                           000003   278  CLK_PCKENR1_UART1 = (3)
                           000001   279  CLK_PCKENR1_SPI = (1)
                           000000   280  CLK_PCKENR1_I2C = (0)
                                    281 ; CLK_PCKENR2
                           000003   282  CLK_PCKENR2_ADC1 = (3)
                           000002   283  CLK_PCKENR2_AWU = (2)
                                    284 
                                    285 ; Clock bits
                           000005   286  CLK_ICKR_REGAH = (5)
                           000004   287  CLK_ICKR_LSIRDY = (4)
                           000003   288  CLK_ICKR_LSIEN = (3)
                           000002   289  CLK_ICKR_FHW = (2)
                           000001   290  CLK_ICKR_HSIRDY = (1)
                           000000   291  CLK_ICKR_HSIEN = (0)
                                    292 
                           000001   293  CLK_ECKR_HSERDY = (1)
                           000000   294  CLK_ECKR_HSEEN = (0)
                                    295 ; clock source
                           0000E1   296  CLK_SWR_HSI = 0xE1
                           0000D2   297  CLK_SWR_LSI = 0xD2
                           0000B4   298  CLK_SWR_HSE = 0xB4
                                    299 
                           000003   300  CLK_SWCR_SWIF = (3)
                           000002   301  CLK_SWCR_SWIEN = (2)
                           000001   302  CLK_SWCR_SWEN = (1)
                           000000   303  CLK_SWCR_SWBSY = (0)
                                    304 
                           000004   305  CLK_CKDIVR_HSIDIV1 = (4)
                           000003   306  CLK_CKDIVR_HSIDIV0 = (3)
                           000002   307  CLK_CKDIVR_CPUDIV2 = (2)
                           000001   308  CLK_CKDIVR_CPUDIV1 = (1)
                           000000   309  CLK_CKDIVR_CPUDIV0 = (0)
                                    310 
                                    311 ; Watchdog
                           0050D1   312  WWDG_CR  = (0x50D1)
                           0050D2   313  WWDG_WR  = (0x50D2)
                           0050E0   314  IWDG_KR  = (0x50E0)
                           0050E1   315  IWDG_PR  = (0x50E1)
                           0050E2   316  IWDG_RLR  = (0x50E2)
                           0050F0   317  AWU_CSR1  = (0x50F0)
                           0050F1   318  AWU_APR  = (0x50F1)
                           0050F2   319  AWU_TBR  = (0x50F2)
                                    320 
                                    321 ; Beep
                           0050F3   322  BEEP_CSR  = (0x50F3)
                                    323 
                                    324 ; SPI
                           005200   325  SPI_CR1  = (0x5200)
                           005201   326  SPI_CR2  = (0x5201)
                           005202   327  SPI_ICR  = (0x5202)
                           005203   328  SPI_SR  = (0x5203)
                           005204   329  SPI_DR  = (0x5204)

ASxxxx Assembler V02.00 + NoICE + SDCC mods  (STMicroelectronics STM8), page 11.
Hexadecimal [24-Bits]

                           005205   330  SPI_CRCPR  = (0x5205)
                           005206   331  SPI_RXCRCR  = (0x5206)
                           005207   332  SPI_TXCRCR  = (0x5207)
                                    333 
                                    334 ; I2C
                           005210   335  I2C_CR1  = (0x5210)
                           005211   336  I2C_CR2  = (0x5211)
                           005212   337  I2C_FREQR  = (0x5212)
                           005213   338  I2C_OARL  = (0x5213)
                           005214   339  I2C_OARH  = (0x5214)
                           005216   340  I2C_DR  = (0x5216)
                           005217   341  I2C_SR1  = (0x5217)
                           005218   342  I2C_SR2  = (0x5218)
                           005219   343  I2C_SR3  = (0x5219)
                           00521A   344  I2C_ITR  = (0x521A)
                           00521B   345  I2C_CCRL  = (0x521B)
                           00521C   346  I2C_CCRH  = (0x521C)
                           00521D   347  I2C_TRISER  = (0x521D)
                           00521E   348  I2C_PECR  = (0x521E)
                                    349 
                           000007   350  I2C_CR1_NOSTRETCH = (7)
                           000006   351  I2C_CR1_ENGC = (6)
                           000000   352  I2C_CR1_PE = (0)
                                    353 
                           000007   354  I2C_CR2_SWRST = (7)
                           000003   355  I2C_CR2_POS = (3)
                           000002   356  I2C_CR2_ACK = (2)
                           000001   357  I2C_CR2_STOP = (1)
                           000000   358  I2C_CR2_START = (0)
                                    359 
                           000000   360  I2C_OARL_ADD0 = (0)
                                    361 
                           000009   362  I2C_OAR_ADDR_7BIT = ((I2C_OARL & 0xFE) >> 1)
                           000813   363  I2C_OAR_ADDR_10BIT = (((I2C_OARH & 0x06) << 9) | (I2C_OARL & 0xFF))
                                    364 
                           000007   365  I2C_OARH_ADDMODE = (7)
                           000006   366  I2C_OARH_ADDCONF = (6)
                           000002   367  I2C_OARH_ADD9 = (2)
                           000001   368  I2C_OARH_ADD8 = (1)
                                    369 
                           000007   370  I2C_SR1_TXE = (7)
                           000006   371  I2C_SR1_RXNE = (6)
                           000004   372  I2C_SR1_STOPF = (4)
                           000003   373  I2C_SR1_ADD10 = (3)
                           000002   374  I2C_SR1_BTF = (2)
                           000001   375  I2C_SR1_ADDR = (1)
                           000000   376  I2C_SR1_SB = (0)
                                    377 
                           000005   378  I2C_SR2_WUFH = (5)
                           000003   379  I2C_SR2_OVR = (3)
                           000002   380  I2C_SR2_AF = (2)
                           000001   381  I2C_SR2_ARLO = (1)
                           000000   382  I2C_SR2_BERR = (0)
                                    383 
                           000007   384  I2C_SR3_DUALF = (7)

ASxxxx Assembler V02.00 + NoICE + SDCC mods  (STMicroelectronics STM8), page 12.
Hexadecimal [24-Bits]

                           000004   385  I2C_SR3_GENCALL = (4)
                           000002   386  I2C_SR3_TRA = (2)
                           000001   387  I2C_SR3_BUSY = (1)
                           000000   388  I2C_SR3_MSL = (0)
                                    389 
                           000002   390  I2C_ITR_ITBUFEN = (2)
                           000001   391  I2C_ITR_ITEVTEN = (1)
                           000000   392  I2C_ITR_ITERREN = (0)
                                    393 
                                    394 ; Precalculated values, all in KHz
                           000080   395  I2C_CCRH_16MHZ_FAST_400 = 0x80
                           00000D   396  I2C_CCRL_16MHZ_FAST_400 = 0x0D
                                    397 ;
                                    398 ; Fast I2C mode max rise time = 300ns
                                    399 ; I2C_FREQR = 16 = (MHz) => tMASTER = 1/16 = 62.5 ns
                                    400 ; TRISER = = (300/62.5) + 1 = floor(4.8) + 1 = 5.
                                    401 
                           000005   402  I2C_TRISER_16MHZ_FAST_400 = 0x05
                                    403 
                           0000C0   404  I2C_CCRH_16MHZ_FAST_320 = 0xC0
                           000002   405  I2C_CCRL_16MHZ_FAST_320 = 0x02
                           000005   406  I2C_TRISER_16MHZ_FAST_320 = 0x05
                                    407 
                           000080   408  I2C_CCRH_16MHZ_FAST_200 = 0x80
                           00001A   409  I2C_CCRL_16MHZ_FAST_200 = 0x1A
                           000005   410  I2C_TRISER_16MHZ_FAST_200 = 0x05
                                    411 
                           000000   412  I2C_CCRH_16MHZ_STD_100 = 0x00
                           000050   413  I2C_CCRL_16MHZ_STD_100 = 0x50
                                    414 ;
                                    415 ; Standard I2C mode max rise time = 1000ns
                                    416 ; I2C_FREQR = 16 = (MHz) => tMASTER = 1/16 = 62.5 ns
                                    417 ; TRISER = = (1000/62.5) + 1 = floor(16) + 1 = 17.
                                    418 
                           000011   419  I2C_TRISER_16MHZ_STD_100 = 0x11
                                    420 
                           000000   421  I2C_CCRH_16MHZ_STD_50 = 0x00
                           0000A0   422  I2C_CCRL_16MHZ_STD_50 = 0xA0
                           000011   423  I2C_TRISER_16MHZ_STD_50 = 0x11
                                    424 
                           000001   425  I2C_CCRH_16MHZ_STD_20 = 0x01
                           000090   426  I2C_CCRL_16MHZ_STD_20 = 0x90
                           000011   427  I2C_TRISER_16MHZ_STD_20 = 0x11;
                                    428 
                           000001   429  I2C_READ = 1
                           000000   430  I2C_WRITE = 0
                                    431 
                                    432 ; baudrate constant for brr_value table access
                           000000   433 B2400=0
                           000001   434 B4800=1
                           000002   435 B9600=2
                           000003   436 B19200=3
                           000004   437 B38400=4
                           000005   438 B57600=5
                           000006   439 B115200=6

ASxxxx Assembler V02.00 + NoICE + SDCC mods  (STMicroelectronics STM8), page 13.
Hexadecimal [24-Bits]

                           000007   440 B230400=7
                           000008   441 B460800=8
                           000009   442 B921600=9
                                    443 
                                    444 ; UART1
                           005230   445  UART1_SR    = (0x5230)
                           005231   446  UART1_DR    = (0x5231)
                           005232   447  UART1_BRR1  = (0x5232)
                           005233   448  UART1_BRR2  = (0x5233)
                           005234   449  UART1_CR1   = (0x5234)
                           005235   450  UART1_CR2   = (0x5235)
                           005236   451  UART1_CR3   = (0x5236)
                           005237   452  UART1_CR4   = (0x5237)
                           005238   453  UART1_CR5   = (0x5238)
                           005239   454  UART1_GTR   = (0x5239)
                           00523A   455  UART1_PSCR  = (0x523A)
                                    456 
                           000002   457  UART1_TX_PIN = 2 ; PD5
                           000003   458  UART1_RX_PIN = 3 ; PD6 
                           00500F   459  UART1_PORT = GPIO_BASE+PD 
                                    460 
                                    461 ; UART Status Register bits
                           000007   462  UART_SR_TXE = (7)
                           000006   463  UART_SR_TC = (6)
                           000005   464  UART_SR_RXNE = (5)
                           000004   465  UART_SR_IDLE = (4)
                           000003   466  UART_SR_OR = (3)
                           000002   467  UART_SR_NF = (2)
                           000001   468  UART_SR_FE = (1)
                           000000   469  UART_SR_PE = (0)
                                    470 
                                    471 ; Uart Control Register bits
                           000007   472  UART_CR1_R8 = (7)
                           000006   473  UART_CR1_T8 = (6)
                           000005   474  UART_CR1_UARTD = (5)
                           000004   475  UART_CR1_M = (4)
                           000003   476  UART_CR1_WAKE = (3)
                           000002   477  UART_CR1_PCEN = (2)
                           000001   478  UART_CR1_PS = (1)
                           000000   479  UART_CR1_PIEN = (0)
                                    480 
                           000007   481  UART_CR2_TIEN = (7)
                           000006   482  UART_CR2_TCIEN = (6)
                           000005   483  UART_CR2_RIEN = (5)
                           000004   484  UART_CR2_ILIEN = (4)
                           000003   485  UART_CR2_TEN = (3)
                           000002   486  UART_CR2_REN = (2)
                           000001   487  UART_CR2_RWU = (1)
                           000000   488  UART_CR2_SBK = (0)
                                    489 
                           000006   490  UART_CR3_LINEN = (6)
                           000005   491  UART_CR3_STOP1 = (5)
                           000004   492  UART_CR3_STOP0 = (4)
                           000003   493  UART_CR3_CLKEN = (3)
                           000002   494  UART_CR3_CPOL = (2)

ASxxxx Assembler V02.00 + NoICE + SDCC mods  (STMicroelectronics STM8), page 14.
Hexadecimal [24-Bits]

                           000001   495  UART_CR3_CPHA = (1)
                           000000   496  UART_CR3_LBCL = (0)
                                    497 
                           000006   498  UART_CR4_LBDIEN = (6)
                           000005   499  UART_CR4_LBDL = (5)
                           000004   500  UART_CR4_LBDF = (4)
                           000003   501  UART_CR4_ADD3 = (3)
                           000002   502  UART_CR4_ADD2 = (2)
                           000001   503  UART_CR4_ADD1 = (1)
                           000000   504  UART_CR4_ADD0 = (0)
                                    505 
                           000005   506  UART_CR5_SCEN = (5)
                           000004   507  UART_CR5_NACK = (4)
                           000003   508  UART_CR5_HDSEL = (3)
                           000002   509  UART_CR5_IRLP = (2)
                           000001   510  UART_CR5_IREN = (1)
                                    511 
                                    512 ; TIMERS
                                    513 ; Timer 1 - 16-bit timer with complementary PWM outputs
                           005250   514  TIM1_CR1  = (0x5250)
                           005251   515  TIM1_CR2  = (0x5251)
                           005252   516  TIM1_SMCR  = (0x5252)
                           005253   517  TIM1_ETR  = (0x5253)
                           005254   518  TIM1_IER  = (0x5254)
                           005255   519  TIM1_SR1  = (0x5255)
                           005256   520  TIM1_SR2  = (0x5256)
                           005257   521  TIM1_EGR  = (0x5257)
                           005258   522  TIM1_CCMR1  = (0x5258)
                           005259   523  TIM1_CCMR2  = (0x5259)
                           00525A   524  TIM1_CCMR3  = (0x525A)
                           00525B   525  TIM1_CCMR4  = (0x525B)
                           00525C   526  TIM1_CCER1  = (0x525C)
                           00525D   527  TIM1_CCER2  = (0x525D)
                           00525E   528  TIM1_CNTRH  = (0x525E)
                           00525F   529  TIM1_CNTRL  = (0x525F)
                           005260   530  TIM1_PSCRH  = (0x5260)
                           005261   531  TIM1_PSCRL  = (0x5261)
                           005262   532  TIM1_ARRH  = (0x5262)
                           005263   533  TIM1_ARRL  = (0x5263)
                           005264   534  TIM1_RCR  = (0x5264)
                           005265   535  TIM1_CCR1H  = (0x5265)
                           005266   536  TIM1_CCR1L  = (0x5266)
                           005267   537  TIM1_CCR2H  = (0x5267)
                           005268   538  TIM1_CCR2L  = (0x5268)
                           005269   539  TIM1_CCR3H  = (0x5269)
                           00526A   540  TIM1_CCR3L  = (0x526A)
                           00526B   541  TIM1_CCR4H  = (0x526B)
                           00526C   542  TIM1_CCR4L  = (0x526C)
                           00526D   543  TIM1_BKR  = (0x526D)
                           00526E   544  TIM1_DTR  = (0x526E)
                           00526F   545  TIM1_OISR  = (0x526F)
                                    546 
                                    547 ; Timer Control Register bits
                           000007   548  TIM_CR1_ARPE = (7)
                           000006   549  TIM_CR1_CMSH = (6)

ASxxxx Assembler V02.00 + NoICE + SDCC mods  (STMicroelectronics STM8), page 15.
Hexadecimal [24-Bits]

                           000005   550  TIM_CR1_CMSL = (5)
                           000004   551  TIM_CR1_DIR = (4)
                           000003   552  TIM_CR1_OPM = (3)
                           000002   553  TIM_CR1_URS = (2)
                           000001   554  TIM_CR1_UDIS = (1)
                           000000   555  TIM_CR1_CEN = (0)
                                    556 
                           000006   557  TIM1_CR2_MMS2 = (6)
                           000005   558  TIM1_CR2_MMS1 = (5)
                           000004   559  TIM1_CR2_MMS0 = (4)
                           000002   560  TIM1_CR2_COMS = (2)
                           000000   561  TIM1_CR2_CCPC = (0)
                                    562 
                                    563 ; Timer Slave Mode Control bits
                           000007   564  TIM1_SMCR_MSM = (7)
                           000006   565  TIM1_SMCR_TS2 = (6)
                           000005   566  TIM1_SMCR_TS1 = (5)
                           000004   567  TIM1_SMCR_TS0 = (4)
                           000002   568  TIM1_SMCR_SMS2 = (2)
                           000001   569  TIM1_SMCR_SMS1 = (1)
                           000000   570  TIM1_SMCR_SMS0 = (0)
                                    571 
                                    572 ; Timer External Trigger Enable bits
                           000007   573  TIM1_ETR_ETP = (7)
                           000006   574  TIM1_ETR_ECE = (6)
                           000005   575  TIM1_ETR_ETPS1 = (5)
                           000004   576  TIM1_ETR_ETPS0 = (4)
                           000003   577  TIM1_ETR_ETF3 = (3)
                           000002   578  TIM1_ETR_ETF2 = (2)
                           000001   579  TIM1_ETR_ETF1 = (1)
                           000000   580  TIM1_ETR_ETF0 = (0)
                                    581 
                                    582 ; Timer Interrupt Enable bits
                           000007   583  TIM1_IER_BIE = (7)
                           000006   584  TIM1_IER_TIE = (6)
                           000005   585  TIM1_IER_COMIE = (5)
                           000004   586  TIM1_IER_CC4IE = (4)
                           000003   587  TIM1_IER_CC3IE = (3)
                           000002   588  TIM1_IER_CC2IE = (2)
                           000001   589  TIM1_IER_CC1IE = (1)
                           000000   590  TIM1_IER_UIE = (0)
                                    591 
                                    592 ; Timer Status Register bits
                           000007   593  TIM1_SR1_BIF = (7)
                           000006   594  TIM1_SR1_TIF = (6)
                           000005   595  TIM1_SR1_COMIF = (5)
                           000004   596  TIM1_SR1_CC4IF = (4)
                           000003   597  TIM1_SR1_CC3IF = (3)
                           000002   598  TIM1_SR1_CC2IF = (2)
                           000001   599  TIM1_SR1_CC1IF = (1)
                           000000   600  TIM1_SR1_UIF = (0)
                                    601 
                           000004   602  TIM1_SR2_CC4OF = (4)
                           000003   603  TIM1_SR2_CC3OF = (3)
                           000002   604  TIM1_SR2_CC2OF = (2)

ASxxxx Assembler V02.00 + NoICE + SDCC mods  (STMicroelectronics STM8), page 16.
Hexadecimal [24-Bits]

                           000001   605  TIM1_SR2_CC1OF = (1)
                                    606 
                                    607 ; Timer Event Generation Register bits
                           000007   608  TIM_EGR_BG = (7)
                           000006   609  TIM_EGR_TG = (6)
                           000005   610  TIM_EGR_COMG = (5)
                           000004   611  TIM_EGR_CC4G = (4)
                           000003   612  TIM_EGR_CC3G = (3)
                           000002   613  TIM_EGR_CC2G = (2)
                           000001   614  TIM_EGR_CC1G = (1)
                           000000   615  TIM_EGR_UG = (0)
                                    616 
                                    617 ; timer capture compare enable register 
                                    618 ; bit fields 
                           000000   619 TIM_CCER1_CC1E=0 
                           000001   620 TIM_CCER1_CC1P=1 
                           000002   621 TIM_CCER1_CC1NE=2
                           000003   622 TIM_CCER1_CC2NP=3
                           000004   623 TIM_CCER1_CC2E=4 
                           000005   624 TIM_CCER1_CC2P=5
                           000006   625 TIM_CCER1_CC2NE=6
                           000007   626 TIM_CCER1_CC2NP=7
                           000000   627 TIM_CCER2_CC3E=0 
                           000001   628 TIM_CCER2_CC3P=1 
                           000002   629 TIM_CCER2_CC2NE=2
                           000003   630 TIM_CCER2_CC2NP=3
                           000004   631 TIM_CCER2_CC4E=4
                           000005   632 TIM_CCER2_CC4P=5 
                                    633 
                                    634 
                                    635 ; Capture/Compare Mode Register 1 - channel configured in output
                           000007   636  TIM1_CCMR1_OC1CE = (7)
                           000006   637  TIM1_CCMR1_OC1M2 = (6)
                           000005   638  TIM1_CCMR1_OC1M1 = (5)
                           000004   639  TIM1_CCMR1_OC1M0 = (4)
                           000003   640  TIM1_CCMR1_OC1PE = (3)
                           000002   641  TIM1_CCMR1_OC1FE = (2)
                           000001   642  TIM1_CCMR1_CC1S1 = (1)
                           000000   643  TIM1_CCMR1_CC1S0 = (0)
                                    644 
                                    645 ; Capture/Compare Mode Register 1 - channel configured in input
                           000007   646  TIM1_CCMR1_IC1F3 = (7)
                           000006   647  TIM1_CCMR1_IC1F2 = (6)
                           000005   648  TIM1_CCMR1_IC1F1 = (5)
                           000004   649  TIM1_CCMR1_IC1F0 = (4)
                           000003   650  TIM1_CCMR1_IC1PSC1 = (3)
                           000002   651  TIM1_CCMR1_IC1PSC0 = (2)
                                    652 ;  TIM1_CCMR1_CC1S1 = (1)
                           000000   653  TIM1_CCMR1_CC1S0 = (0)
                                    654 
                                    655 ; Capture/Compare Mode Register 2 - channel configured in output
                           000007   656  TIM1_CCMR2_OC2CE = (7)
                           000006   657  TIM1_CCMR2_OC2M2 = (6)
                           000005   658  TIM1_CCMR2_OC2M1 = (5)
                           000004   659  TIM1_CCMR2_OC2M0 = (4)

ASxxxx Assembler V02.00 + NoICE + SDCC mods  (STMicroelectronics STM8), page 17.
Hexadecimal [24-Bits]

                           000003   660  TIM1_CCMR2_OC2PE = (3)
                           000002   661  TIM1_CCMR2_OC2FE = (2)
                           000001   662  TIM1_CCMR2_CC2S1 = (1)
                           000000   663  TIM1_CCMR2_CC2S0 = (0)
                                    664 
                                    665 ; Capture/Compare Mode Register 2 - channel configured in input
                           000007   666  TIM1_CCMR2_IC2F3 = (7)
                           000006   667  TIM1_CCMR2_IC2F2 = (6)
                           000005   668  TIM1_CCMR2_IC2F1 = (5)
                           000004   669  TIM1_CCMR2_IC2F0 = (4)
                           000003   670  TIM1_CCMR2_IC2PSC1 = (3)
                           000002   671  TIM1_CCMR2_IC2PSC0 = (2)
                                    672 ;  TIM1_CCMR2_CC2S1 = (1)
                           000000   673  TIM1_CCMR2_CC2S0 = (0)
                                    674 
                                    675 ; Capture/Compare Mode Register 3 - channel configured in output
                           000007   676  TIM1_CCMR3_OC3CE = (7)
                           000006   677  TIM1_CCMR3_OC3M2 = (6)
                           000005   678  TIM1_CCMR3_OC3M1 = (5)
                           000004   679  TIM1_CCMR3_OC3M0 = (4)
                           000003   680  TIM1_CCMR3_OC3PE = (3)
                           000002   681  TIM1_CCMR3_OC3FE = (2)
                           000001   682  TIM1_CCMR3_CC3S1 = (1)
                           000000   683  TIM1_CCMR3_CC3S0 = (0)
                                    684 
                                    685 ; Capture/Compare Mode Register 3 - channel configured in input
                           000007   686  TIM1_CCMR3_IC3F3 = (7)
                           000006   687  TIM1_CCMR3_IC3F2 = (6)
                           000005   688  TIM1_CCMR3_IC3F1 = (5)
                           000004   689  TIM1_CCMR3_IC3F0 = (4)
                           000003   690  TIM1_CCMR3_IC3PSC1 = (3)
                           000002   691  TIM1_CCMR3_IC3PSC0 = (2)
                                    692 ;  TIM1_CCMR3_CC3S1 = (1)
                           000000   693  TIM1_CCMR3_CC3S0 = (0)
                                    694 
                                    695 ; Capture/Compare Mode Register 4 - channel configured in output
                           000007   696  TIM1_CCMR4_OC4CE = (7)
                           000006   697  TIM1_CCMR4_OC4M2 = (6)
                           000005   698  TIM1_CCMR4_OC4M1 = (5)
                           000004   699  TIM1_CCMR4_OC4M0 = (4)
                           000003   700  TIM1_CCMR4_OC4PE = (3)
                           000002   701  TIM1_CCMR4_OC4FE = (2)
                           000001   702  TIM1_CCMR4_CC4S1 = (1)
                           000000   703  TIM1_CCMR4_CC4S0 = (0)
                                    704 
                                    705 ; Capture/Compare Mode Register 4 - channel configured in input
                           000007   706  TIM1_CCMR4_IC4F3 = (7)
                           000006   707  TIM1_CCMR4_IC4F2 = (6)
                           000005   708  TIM1_CCMR4_IC4F1 = (5)
                           000004   709  TIM1_CCMR4_IC4F0 = (4)
                           000003   710  TIM1_CCMR4_IC4PSC1 = (3)
                           000002   711  TIM1_CCMR4_IC4PSC0 = (2)
                                    712 ;  TIM1_CCMR4_CC4S1 = (1)
                           000000   713  TIM1_CCMR4_CC4S0 = (0)
                                    714 

ASxxxx Assembler V02.00 + NoICE + SDCC mods  (STMicroelectronics STM8), page 18.
Hexadecimal [24-Bits]

                                    715 ; timer 1 break register bits 
                           000000   716 TIM1_BKR_LOCK=0 ;(0:1) lock configuration
                           000002   717 TIM1_BKR_OSSI=2 ; Off state selection for idle mode
                           000003   718 TIM1_BKR_OSSR=3 ; Off state selection for Run mode
                           000004   719 TIM1_BKR_BKE=4  ; Break enable
                           000005   720 TIM1_BKR_BKP=5  ; Break polarity
                           000006   721 TIM1_BKR_AOE=6  ; Automatic output enable
                           000007   722 TIM1_BKR_MOE=7  ; Main output enable
                                    723 
                                    724 ; timer 1 output idle state register bits 
                           000000   725 TIM1_OISR_OS1=0 
                           000001   726 TIM1_OISR_OSN1=1 
                           000002   727 TIM1_OISR_OS2=2 
                           000003   728 TIM1_OISR_OSN2=3 
                           000004   729 TIM1_OISR_OS3=4 
                           000005   730 TIM1_OISR_OSN3=5
                           000006   731 TIM1_OISR_OS4=6 
                           000007   732 TIM1_OISR_OSN4=7
                                    733 
                                    734 ; Timer 2 - 16-bit timer
                           005300   735  TIM2_CR1  = (0x5300)
                           005303   736  TIM2_IER  = (0x5303)
                           005304   737  TIM2_SR1  = (0x5304)
                           005305   738  TIM2_SR2  = (0x5305)
                           005306   739  TIM2_EGR  = (0x5306)
                           005307   740  TIM2_CCMR1  = (0x5307)
                           005308   741  TIM2_CCMR2  = (0x5308)
                           005309   742  TIM2_CCMR3  = (0x5309)
                           00530A   743  TIM2_CCER1  = (0x530A)
                           00530B   744  TIM2_CCER2  = (0x530B)
                           00530C   745  TIM2_CNTRH  = (0x530C)
                           00530C   746  TIM2_CNTRL  = (0x530C)
                           00530E   747  TIM2_PSCR  = (0x530E)
                           00530F   748  TIM2_ARRH  = (0x530F)
                           005319   749  TIM2_ARRL  = (0x5319)
                           005311   750  TIM2_CCR1H  = (0x5311)
                           005312   751  TIM2_CCR1L  = (0x5312)
                           005313   752  TIM2_CCR2H  = (0x5313)
                           005314   753  TIM2_CCR2L  = (0x5314)
                           005315   754  TIM2_CCR3H  = (0x5315)
                           005316   755  TIM2_CCR3L  = (0x5316)
                                    756 
                                    757 ; Timer 4
                           005340   758  TIM4_CR1  = (0x5340)
                           005343   759  TIM4_IER  = (0x5343)
                           005344   760  TIM4_SR  = (0x5344)
                           005345   761  TIM4_EGR  = (0x5345)
                           005346   762  TIM4_CNTR  = (0x5346)
                           005347   763  TIM4_PSCR  = (0x5347)
                           005348   764  TIM4_ARR  = (0x5348)
                                    765 
                                    766 ; Timer 4 bitmasks
                                    767 
                           000007   768  TIM4_CR1_ARPE = (7)
                           000003   769  TIM4_CR1_OPM = (3)

ASxxxx Assembler V02.00 + NoICE + SDCC mods  (STMicroelectronics STM8), page 19.
Hexadecimal [24-Bits]

                           000002   770  TIM4_CR1_URS = (2)
                           000001   771  TIM4_CR1_UDIS = (1)
                           000000   772  TIM4_CR1_CEN = (0)
                                    773 
                           000000   774  TIM4_IER_UIE = (0)
                                    775 
                           000000   776  TIM4_SR_UIF = (0)
                                    777 
                           000000   778  TIM4_EGR_UG = (0)
                                    779 
                           000002   780  TIM4_PSCR_PSC2 = (2)
                           000001   781  TIM4_PSCR_PSC1 = (1)
                           000000   782  TIM4_PSCR_PSC0 = (0)
                                    783 
                           000000   784  TIM4_PSCR_1 = 0
                           000001   785  TIM4_PSCR_2 = 1
                           000002   786  TIM4_PSCR_4 = 2
                           000003   787  TIM4_PSCR_8 = 3
                           000004   788  TIM4_PSCR_16 = 4
                           000005   789  TIM4_PSCR_32 = 5
                           000006   790  TIM4_PSCR_64 = 6
                           000007   791  TIM4_PSCR_128 = 7
                                    792 
                                    793 ; TIMx_CCMRx bit fields 
                           000004   794 TIMx_CCRM1_OC1M=4
                           000003   795 TIMx_CCRM1_OC1PE=3 
                           000000   796 TIMx_CCRM1_CC1S=0 
                                    797 
                                    798 ; ADC1 individual element access
                           0053E0   799  ADC1_DB0RH  = (0x53E0)
                           0053E1   800  ADC1_DB0RL  = (0x53E1)
                           0053E2   801  ADC1_DB1RH  = (0x53E2)
                           0053E3   802  ADC1_DB1RL  = (0x53E3)
                           0053E4   803  ADC1_DB2RH  = (0x53E4)
                           0053E5   804  ADC1_DB2RL  = (0x53E5)
                           0053E6   805  ADC1_DB3RH  = (0x53E6)
                           0053E7   806  ADC1_DB3RL  = (0x53E7)
                           0053E8   807  ADC1_DB4RH  = (0x53E8)
                           0053E9   808  ADC1_DB4RL  = (0x53E9)
                           0053EA   809  ADC1_DB5RH  = (0x53EA)
                           0053EB   810  ADC1_DB5RL  = (0x53EB)
                           0053EC   811  ADC1_DB6RH  = (0x53EC)
                           0053ED   812  ADC1_DB6RL  = (0x53ED)
                           0053EE   813  ADC1_DB7RH  = (0x53EE)
                           0053EF   814  ADC1_DB7RL  = (0x53EF)
                           0053F0   815  ADC1_DB8RH  = (0x53F0)
                           0053F1   816  ADC1_DB8RL  = (0x53F1)
                           0053F2   817  ADC1_DB9RH  = (0x53F2)
                           0053F3   818  ADC1_DB9RL  = (0x53F3)
                                    819 
                           005400   820  ADC1_CSR  = (0x5400)
                           005401   821  ADC1_CR1  = (0x5401)
                           005402   822  ADC1_CR2  = (0x5402)
                           005403   823  ADC1_CR3  = (0x5403)
                           005404   824  ADC1_DRH  = (0x5404)

ASxxxx Assembler V02.00 + NoICE + SDCC mods  (STMicroelectronics STM8), page 20.
Hexadecimal [24-Bits]

                           005405   825  ADC1_DRL  = (0x5405)
                           005406   826  ADC1_TDRH  = (0x5406)
                           005407   827  ADC1_TDRL  = (0x5407)
                           005408   828  ADC1_HTRH  = (0x5408)
                           005409   829  ADC1_HTRL  = (0x5409)
                           00540A   830  ADC1_LTRH  = (0x540A)
                           00540B   831  ADC1_LTRL  = (0x540B)
                           00540C   832  ADC1_AWSRH  = (0x540C)
                           00540D   833  ADC1_AWSRL  = (0x540D)
                           00540E   834  ADC1_AWCRH  = (0x540E)
                           00540F   835  ADC1_AWCRL  = (0x540F)
                                    836 
                                    837 ; ADC1 bitmasks
                                    838 
                           000007   839  ADC1_CSR_EOC = (7)
                           000006   840  ADC1_CSR_AWD = (6)
                           000005   841  ADC1_CSR_EOCIE = (5)
                           000004   842  ADC1_CSR_AWDIE = (4)
                           000003   843  ADC1_CSR_CH3 = (3)
                           000002   844  ADC1_CSR_CH2 = (2)
                           000001   845  ADC1_CSR_CH1 = (1)
                           000000   846  ADC1_CSR_CH0 = (0)
                                    847 
                           000006   848  ADC1_CR1_SPSEL2 = (6)
                           000005   849  ADC1_CR1_SPSEL1 = (5)
                           000004   850  ADC1_CR1_SPSEL0 = (4)
                           000001   851  ADC1_CR1_CONT = (1)
                           000000   852  ADC1_CR1_ADON = (0)
                                    853 
                           000006   854  ADC1_CR2_EXTTRIG = (6)
                           000005   855  ADC1_CR2_EXTSEL1 = (5)
                           000004   856  ADC1_CR2_EXTSEL0 = (4)
                           000003   857  ADC1_CR2_ALIGN = (3)
                           000001   858  ADC1_CR2_SCAN = (1)
                                    859 
                           000007   860  ADC1_CR3_DBUF = (7)
                           000006   861  ADC1_CR3_DRH = (6)
                                    862 
                                    863 ; CPU
                           007F00   864  CPU_A  = (0x7F00)
                           007F01   865  CPU_PCE  = (0x7F01)
                           007F02   866  CPU_PCH  = (0x7F02)
                           007F03   867  CPU_PCL  = (0x7F03)
                           007F04   868  CPU_XH  = (0x7F04)
                           007F05   869  CPU_XL  = (0x7F05)
                           007F06   870  CPU_YH  = (0x7F06)
                           007F07   871  CPU_YL  = (0x7F07)
                           007F08   872  CPU_SPH  = (0x7F08)
                           007F09   873  CPU_SPL   = (0x7F09)
                           007F0A   874  CPU_CCR   = (0x7F0A)
                                    875 
                                    876 ; global configuration register
                           007F60   877  CFG_GCR   = (0x7F60)
                                    878 
                                    879 ; interrupt control registers

ASxxxx Assembler V02.00 + NoICE + SDCC mods  (STMicroelectronics STM8), page 21.
Hexadecimal [24-Bits]

                           007F70   880  ITC_SPR1   = (0x7F70)
                           007F71   881  ITC_SPR2   = (0x7F71)
                           007F72   882  ITC_SPR3   = (0x7F72)
                           007F73   883  ITC_SPR4   = (0x7F73)
                           007F74   884  ITC_SPR5   = (0x7F74)
                           007F75   885  ITC_SPR6   = (0x7F75)
                           007F76   886  ITC_SPR7   = (0x7F76)
                           007F77   887  ITC_SPR8   = (0x7F77)
                                    888 ; interrupt priority
                           000002   889  IPR0 = 2
                           000001   890  IPR1 = 1
                           000000   891  IPR2 = 0
                           000003   892  IPR3 = 3 
                           000003   893  IPR_MASK = 3
                                    894 
                                    895 ; SWIM, control and status register
                           007F80   896  SWIM_CSR   = (0x7F80)
                                    897 ; debug registers
                           007F90   898  DM_BK1RE   = (0x7F90)
                           007F91   899  DM_BK1RH   = (0x7F91)
                           007F92   900  DM_BK1RL   = (0x7F92)
                           007F93   901  DM_BK2RE   = (0x7F93)
                           007F94   902  DM_BK2RH   = (0x7F94)
                           007F95   903  DM_BK2RL   = (0x7F95)
                           007F96   904  DM_CR1   = (0x7F96)
                           007F97   905  DM_CR2   = (0x7F97)
                           007F98   906  DM_CSR1   = (0x7F98)
                           007F99   907  DM_CSR2   = (0x7F99)
                           007F9A   908  DM_ENFCTR   = (0x7F9A)
                                    909 
                                    910 ; Interrupt Numbers
                           000000   911  INT_TLI = 0
                           000001   912  INT_AWU = 1
                           000002   913  INT_CLK = 2
                           000003   914  INT_EXTI0 = 3
                           000004   915  INT_EXTI1 = 4
                           000005   916  INT_EXTI2 = 5
                           000006   917  INT_EXTI3 = 6
                           000007   918  INT_EXTI4 = 7
                           000008   919  INT_RES1 = 8
                           000009   920  INT_RES2 = 9
                           00000A   921  INT_SPI = 10
                           00000B   922  INT_TIM1_OVF = 11
                           00000C   923  INT_TIM1_CCM = 12
                           00000D   924  INT_TIM2_OVF = 13
                           00000E   925  INT_TIM2_CCM = 14
                           00000F   926  INT_RES3 = 15
                           000010   927  INT_RES4 = 16
                           000011   928  INT_UART1_TXC = 17
                           000012   929  INT_UART1_RX_FULL = 18
                           000013   930  INT_I2C = 19
                           000014   931  INT_RES5 = 20
                           000015   932  INT_RES6 = 21
                           000016   933  INT_ADC1 = 22
                           000017   934  INT_TIM4_OVF = 23

ASxxxx Assembler V02.00 + NoICE + SDCC mods  (STMicroelectronics STM8), page 22.
Hexadecimal [24-Bits]

                           000018   935  INT_FLASH = 24
                                    936 
                                    937 ; Interrupt Vectors
                           008000   938  INT_VECTOR_RESET = 0x8000
                           008004   939  INT_VECTOR_TRAP = 0x8004
                           008008   940  INT_VECTOR_TLI = 0x8008
                           00800C   941  INT_VECTOR_AWU = 0x800C
                           008010   942  INT_VECTOR_CLK = 0x8010
                           008014   943  INT_VECTOR_EXTI0 = 0x8014
                           008018   944  INT_VECTOR_EXTI1 = 0x8018
                           00801C   945  INT_VECTOR_EXTI2 = 0x801C
                           008020   946  INT_VECTOR_EXTI3 = 0x8020
                           008024   947  INT_VECTOR_EXTI4 = 0x8024
                           008030   948  INT_VECTOR_SPI = 0x8030
                           008034   949  INT_VECTOR_TIM1_OVF = 0x8034
                           008038   950  INT_VECTOR_TIM1_CCM = 0x8038
                           00803C   951  INT_VECTOR_TIM2_OVF = 0x803C
                           008040   952  INT_VECTOR_TIM2_CCM = 0x8040
                           00804C   953  INT_VECTOR_UART1_TX_COMPLETE = 0x804c
                           008050   954  INT_VECTOR_UART1_RX_FULL = 0x8050
                           008054   955  INT_VECTOR_I2C = 0x8054
                           008060   956  INT_VECTOR_ADC1 = 0x8060
                           008064   957  INT_VECTOR_TIM4_OVF = 0x8064
                           008068   958  INT_VECTOR_FLASH = 0x8068
                                    959 
                                    960  

ASxxxx Assembler V02.00 + NoICE + SDCC mods  (STMicroelectronics STM8), page 23.
Hexadecimal [24-Bits]

                                     12 

ASxxxx Assembler V02.00 + NoICE + SDCC mods  (STMicroelectronics STM8), page 24.
Hexadecimal [24-Bits]

                                     14 
                                     15 ; defined for debug.asm 
                           000000    16 DEBUG=0
                                     17 ; master clock frequency 12Mhz crystal 
                           B71B00    18 FMSTR=12000000 ; 
                                     19 
                                     20 
                                     21 ;;;;;;;;;;;;;;;;;;;;;;;;;;;;;;;;;;;;;;;
                                     22 ; peripherals usage 
                                     23 ;  TIMER4 1 msec timer, use interrupt 
                                     24 ;  TIMER1 CH4  PWM, PC4 pin 14
                                     25 ;  TIMER2 CH1  alarm sound, PD4 pin 1
                                     26 ;  alarm GREEN LED, PC3 pin 13
                                     27 ;  alarm RED LED, PC5 pin 15
                                     28 ;  ADC read AIN3, PD2 pin 19
                                     29 ;;;;;;;;;;;;;;;;;;;;;;;;;;;;;;;;;;;;;;;
                                     30 
                                     31 ;------------------------------
                                     32 ;  system constants 
                                     33 ;------------------------------
                           000005    34 ALARM_RLED_BIT = 5 ; RED LED PC5
                           000003    35 ALARM_GLED_BIT = 3 ; GREEN LED PC3
                           00500A    36 ALARM_LED_ODR = PC_ODR 
                           00500C    37 ALARM_LED_DDR = PC_DDR 
                           00500D    38 ALARM_LED_CR1 = PC_CR1 
                           000004    39 ALARM_SOUND = 4 ; PD4 
                           002EE0    40 ALARM_FREQ_HIGH=FMSTR/1000; 12Mhz/1000 
                           0042F6    41 ALARM_FREQ_LOW=FMSTR/700; 12Mhz/700
                           000003    42 ADC_INPUT = 3
                           00500F    43 ADC_ODR = PD_ODR
                           005011    44 ADC_DDR = PD_DDR 
                           000002    45 ADC_BIT = 2
                                     46 ;; detector sensivity
                                     47 ;; increment to reduce false detection 
                           000002    48 SENSIVITY = 2
                                     49 ; how many samples to skip for average 
                                     50 ; adjustment 
                           000003    51 SKIP_MAX=3
                                     52 
                                     53 ;; period value for TIMER1 frequency 
                                     54 ;; period = 1 msec. 
                           002EE0    55 TMR1_PERIOD= 12000 
                                     56 ; pulse width 12uS 
                           002904    57 TMR1_DC= 12000-1500
                                     58 
                                     59 ;;;;;;;;;;;;;;;;;;;;;;;;
                                     60 ;;  usefull macros 
                                     61 ;;;;;;;;;;;;;;;;;;;;;;;;
                                     62 
                                     63     ; turn on green LED 
                                     64     .macro _gled_on 
                                     65     bres ALARM_LED_ODR,#ALARM_GLED_BIT 
                                     66     .endm 
                                     67 
                                     68     ; turn off green LED 

ASxxxx Assembler V02.00 + NoICE + SDCC mods  (STMicroelectronics STM8), page 25.
Hexadecimal [24-Bits]

                                     69     .macro _gled_off 
                                     70     bset ALARM_LED_ODR,#ALARM_GLED_BIT 
                                     71     .endm 
                                     72 
                                     73     ; turn on red LED 
                                     74     .macro _rled_on 
                                     75     bres ALARM_LED_ODR,#ALARM_RLED_BIT 
                                     76     .endm 
                                     77 
                                     78     ; turn off red LED 
                                     79     .macro _rled_off 
                                     80     bset ALARM_LED_ODR,#ALARM_RLED_BIT 
                                     81     .endm 
                                     82 
                                     83     ; turn on both LED 
                                     84     .macro _leds_on 
                                     85     _gled_on 
                                     86     _rled_on 
                                     87     .endm 
                                     88 
                                     89     ; turn of both LED 
                                     90     .macro _leds_off 
                                     91     _gled_off 
                                     92     _rled_off 
                                     93     .endm 
                                     94 
                                     95     .macro _sound_on     
                                     96  	bset TIM2_CCER1,#TIM_CCER1_CC1E
                                     97 	bset TIM2_CR1,#TIM_CR1_CEN
                                     98 	bset TIM2_EGR,#TIM_EGR_UG
                                     99     .endm 
                                    100 
                                    101     .macro _sound_off 
                                    102 	bres TIM2_CCER1,#TIM_CCER1_CC1E
                                    103 	bres TIM2_CR1,#TIM_CR1_CEN 
                                    104     .endm 
                                    105 
                                    106 ;**********************************************************
                                    107         .area DATA (ABS)
      000000                        108         .org RAM_BASE 
                                    109 ;**********************************************************
      000000                        110 ALARM_DLY: .blkb 1 ; control alarm duration 
      000001                        111 SAMPLES_SUM: .blkw 1   ; sum of ADC reading  
      000003                        112 SAMPLES_AVG: .blkw 1  ; mean of 32 reading  
      000005                        113 CNTDWN: .blkw 1 ; count down timer 
      000007                        114 PERIOD: .blkw 1 ; PWM period count 
      000009                        115 CHANGE: .blkb 1 ; 1=up|-1=down|0=same 
      00000A                        116 COUNT: .blkb 1 ; count changes in same direction 
      00000B                        117 SKIP:  .blkw 1 ; count of sample to skip for average adjust  
      00000D                        118 LAST:  .blkw 1 ; last sample value 
      00000F                        119 SLOPE: .blkw 1 ; inc if DELTA>0 else dec if < 0  
      000011                        120 DELTA: .blkw 1 ; average-last 
                           000000   121 .if DEBUG 
                                    122 RX_CHAR: .blkb 1 ;  keep character received from uart 
                                    123 .endif 

ASxxxx Assembler V02.00 + NoICE + SDCC mods  (STMicroelectronics STM8), page 26.
Hexadecimal [24-Bits]

                                    124 
                                    125 ;**********************************************************
                                    126         .area SSEG (ABS) ; STACK
      001700                        127         .org 0x1700
      001700                        128         .ds 256 
                                    129 ; space for DATSTK,TIB and STACK         
                                    130 ;**********************************************************
                                    131 
                                    132 ;**********************************************************
                                    133         .area HOME ; vectors table
                                    134 ;**********************************************************
      008000 82 00 80 94            135 	int cold_start	        ; reset
      008004 82 00 80 80            136 	int NonHandledInterrupt	; trap
      008008 82 00 80 80            137 	int NonHandledInterrupt	; irq0
      00800C 82 00 80 80            138 	int NonHandledInterrupt	; irq1
      008010 82 00 80 80            139 	int NonHandledInterrupt	; irq2
      008014 82 00 80 80            140 	int NonHandledInterrupt	; irq3
      008018 82 00 80 80            141 	int NonHandledInterrupt	; irq4
      00801C 82 00 80 80            142 	int NonHandledInterrupt	; irq5
      008020 82 00 80 80            143 	int NonHandledInterrupt	; irq6
      008024 82 00 80 80            144 	int NonHandledInterrupt	; irq7
      008028 82 00 80 80            145 	int NonHandledInterrupt	; irq8
      00802C 82 00 80 80            146 	int NonHandledInterrupt	; irq9
      008030 82 00 80 80            147 	int NonHandledInterrupt	; irq10
      008034 82 00 80 80            148 	int NonHandledInterrupt	; irq11
      008038 82 00 80 80            149 	int NonHandledInterrupt	; irq12
      00803C 82 00 80 80            150 	int NonHandledInterrupt	; irq13
      008040 82 00 80 80            151 	int NonHandledInterrupt	; irq14
      008044 82 00 80 80            152 	int NonHandledInterrupt	; irq15
      008048 82 00 80 80            153 	int NonHandledInterrupt	; irq16
      00804C 82 00 80 80            154 	int NonHandledInterrupt	; irq17
                           000000   155 .if DEBUG
                                    156     int uart_rx_handler
                           000001   157 .else 
      008050 82 00 80 80            158 	int NonHandledInterrupt	; irq18
                                    159 .endif 
      008054 82 00 80 80            160 	int NonHandledInterrupt	; irq19
      008058 82 00 80 80            161 	int NonHandledInterrupt	; irq20
      00805C 82 00 80 80            162 	int NonHandledInterrupt	; irq21
      008060 82 00 80 80            163 	int NonHandledInterrupt	; irq22
      008064 82 00 80 86            164 	int Timer4Handler	    ; irq23
      008068 82 00 80 80            165 	int NonHandledInterrupt	; irq24
      00806C 82 00 80 80            166 	int NonHandledInterrupt	; irq25
      008070 82 00 80 80            167 	int NonHandledInterrupt	; irq26
      008074 82 00 80 80            168 	int NonHandledInterrupt	; irq27
      008078 82 00 80 80            169 	int NonHandledInterrupt	; irq28
      00807C 82 00 80 80            170 	int NonHandledInterrupt	; irq29
                                    171 
                                    172 ;**********************************************************
                                    173         .area CODE
                                    174 ;**********************************************************
                                    175 
                                    176 ; non handled interrupt reset MCU
      008080                        177 NonHandledInterrupt:
      008080 80               [11]  178         iret 

ASxxxx Assembler V02.00 + NoICE + SDCC mods  (STMicroelectronics STM8), page 27.
Hexadecimal [24-Bits]

                                    179 
      008081                        180 sofware_reset:
      008081 A6 80            [ 1]  181         ld a, #0x80
      008083 C7 50 D1         [ 1]  182         ld WWDG_CR,a ; WWDG_CR used to reset mcu
                                    183 
                                    184 ; used for count down timer 
      008086                        185 Timer4Handler:
      008086 72 5F 53 44      [ 1]  186 	clr TIM4_SR
      00808A CE 00 05         [ 2]  187     ldw x,CNTDWN 
      00808D 27 04            [ 1]  188     jreq 1$
      00808F 5A               [ 2]  189     decw x 
      008090 CF 00 05         [ 2]  190     ldw CNTDWN,x
      008093                        191 1$:         
      008093 80               [11]  192     iret 
                                    193 
                                    194 
                                    195 ; entry point at power up 
                                    196 ; or reset 
      008094                        197 cold_start: 
                                    198 ; initialize clock to HSE
                                    199 ; no divisor 12 Mhz crystal  
      008094                        200 clock_init:
      008094 9B               [ 1]  201     sim ; disable interrupts 
      008095 72 5F 50 C6      [ 1]  202     clr CLK_CKDIVR
      008099 72 17 50 C5      [ 1]  203     bres CLK_SWCR,#CLK_SWCR_SWIF 
      00809D 35 B4 50 C4      [ 1]  204     mov CLK_SWR,#CLK_SWR_HSE ; 12 Mhz crystal
      0080A1 72 07 50 C5 FB   [ 2]  205     btjf CLK_SWCR,#CLK_SWCR_SWIF,. 
      0080A6 72 12 50 C5      [ 1]  206 	bset CLK_SWCR,#CLK_SWCR_SWEN
                                    207 ; initialize stack pointer 
      0080AA                        208 stack_init: 
      0080AA AE 03 FF         [ 2]  209     ldw x,#RAM_SIZE-1 
      0080AD 94               [ 1]  210     ldw sp,x 
                                    211 ; clear all ram 
      0080AE 7F               [ 1]  212 1$: clr (x)
      0080AF 5A               [ 2]  213     decw x 
      0080B0 26 FC            [ 1]  214     jrne 1$        
                                    215 ; disable all unused peripheral clock
      0080B2 A6 B0            [ 1]  216     ld a,#0xB0 ; enable timers 1,2,4 
      0080B4 C7 50 C7         [ 1]  217     ld CLK_PCKENR1,a 
      0080B7 A6 08            [ 1]  218     ld a,#(1<<3) ; ADC1 
      0080B9 C7 50 CA         [ 1]  219     ld CLK_PCKENR2,a 
                                    220 ; activate pull up on all unused inputs 
                                    221 ; to reduce noise 
      0080BC A6 FF            [ 1]  222 	ld a,#255 
      0080BE C7 50 03         [ 1]  223 	ld PA_CR1,a  
      0080C1 C7 50 08         [ 1]  224  	ld PB_CR1,a
      0080C4 C7 50 17         [ 1]  225 	ld PE_CR1,a 
      0080C7 C7 50 1C         [ 1]  226 	ld PF_CR1,a 
      0080CA A6 C0            [ 1]  227     ld a,#(1<<6)|(1<<7)
      0080CC C7 50 0D         [ 1]  228     ld PC_CR1,a  
      0080CF A6 6A            [ 1]  229     ld a,#(1<<1)|(1<<3)|(1<<5)|(1<<6)
      0080D1 C7 50 12         [ 1]  230 	ld PD_CR1,a    
                                    231 
                                    232 ; set PC4 as output high 
                                    233 ; this is TIM1_CH4 output 

ASxxxx Assembler V02.00 + NoICE + SDCC mods  (STMicroelectronics STM8), page 28.
Hexadecimal [24-Bits]

                                    234 ; want it low when PWM is off     
      0080D4 72 18 50 0C      [ 1]  235     bset PC_DDR,#4 ; output mode 
      0080D8 72 18 50 0A      [ 1]  236     bset PC_ODR,#4 ; high  
                                    237     
                                    238 ; set alarm LED as output 
      0080DC 72 17 50 0D      [ 1]  239     bres ALARM_LED_CR1,#ALARM_GLED_BIT ; open drain 
      0080E0 72 16 50 0C      [ 1]  240     bset ALARM_LED_DDR,#ALARM_GLED_BIT
      0080E4 72 1B 50 0D      [ 1]  241     bres ALARM_LED_CR1,#ALARM_RLED_BIT
      0080E8 72 1A 50 0C      [ 1]  242     bset ALARM_LED_DDR,#ALARM_RLED_BIT  
      00006C                        243     _leds_off     
      00006C                          1     _gled_off 
      0080EC 72 16 50 0A      [ 1]    1     bset ALARM_LED_ODR,#ALARM_GLED_BIT 
      000070                          2     _rled_off 
      0080F0 72 1A 50 0A      [ 1]    1     bset ALARM_LED_ODR,#ALARM_RLED_BIT 
                                    244 
                           000000   245 .if DEBUG 
                                    246     call uart_init 
                                    247 .endif     
                                    248 ; initialize timer4, used for millisecond interrupt  
      0080F4                        249 timer4_init: 
      0080F4 72 11 53 40      [ 1]  250 	bres TIM4_CR1,#TIM4_CR1_CEN 
      0080F8 35 06 53 47      [ 1]  251 	mov TIM4_PSCR,#6 ; prescale 64  
      0080FC 35 BB 53 48      [ 1]  252 	mov TIM4_ARR,#187 ; for 1msec. 12Mhz/64/1000 
      008100 72 10 53 43      [ 1]  253 	bset TIM4_IER,#TIM4_IER_UIE 
      008104 72 10 53 40      [ 1]  254 	bset TIM4_CR1,#TIM4_CR1_CEN
      008108 72 10 53 45      [ 1]  255     bset TIM4_EGR,#TIM4_EGR_UG 
      00810C 9A               [ 1]  256     rim
                                    257 
                                    258 ; initialize TIMER2 for 1Khz tone generator 
      00810D                        259 timer2_init:
      00810D 72 19 50 12      [ 1]  260     bres PD_CR1,#4 ; open drain output 
      008111 35 60 53 07      [ 1]  261  	mov TIM2_CCMR1,#(6<<TIMx_CCRM1_OC1M) ; PWM mode 1 
      008115 35 00 53 0E      [ 1]  262 	mov TIM2_PSCR,#0 ; 
      008119 35 42 53 0F      [ 1]  263     mov TIM2_ARRH,#ALARM_FREQ_LOW>>8  
      00811D 35 F6 53 19      [ 1]  264     mov TIM2_ARRL,#ALARM_FREQ_LOW&255 
      008121 35 21 53 11      [ 1]  265     mov TIM2_CCR1H,#(ALARM_FREQ_LOW/2)>>8
      008125 35 7B 53 12      [ 1]  266     mov TIM2_CCR1L,#(ALARM_FREQ_LOW/2)&255 
      0000A9                        267     _sound_off
      008129 72 11 53 0A      [ 1]    1 	bres TIM2_CCER1,#TIM_CCER1_CC1E
      00812D 72 11 53 00      [ 1]    2 	bres TIM2_CR1,#TIM_CR1_CEN 
                                    268 
                                    269 ; initialize TIMER1 for PWM generation , one pulse mode 
                                    270 ; period 1 msec, pulse width 10uSec 
      008131 AE 2E E0         [ 2]  271     ldw x,#TMR1_PERIOD 
      008134 CF 00 07         [ 2]  272     ldw PERIOD,x 
      008137 72 5F 52 60      [ 1]  273     clr TIM1_PSCRH
      00813B 72 5F 52 61      [ 1]  274     clr TIM1_PSCRL 
      00813F 35 2E 52 62      [ 1]  275     mov TIM1_ARRH,#TMR1_PERIOD>>8  
      008143 35 E0 52 63      [ 1]  276     mov TIM1_ARRL,#TMR1_PERIOD&0xff 
      008147 35 29 52 6B      [ 1]  277     mov TIM1_CCR4H,#TMR1_DC>>8
      00814B 35 04 52 6C      [ 1]  278     mov TIM1_CCR4L,#TMR1_DC&0xff
      00814F 72 1C 52 6F      [ 1]  279     bset TIM1_OISR,#TIM1_OISR_OS4 
      008153 72 18 52 5D      [ 1]  280     bset TIM1_CCER2,#TIM_CCER2_CC4E
      008157 35 68 52 5B      [ 1]  281     mov TIM1_CCMR4,#(6<<4)|(1<<3) ;OC4M=7|OC4PE=1 ; PWM mode 1 
                                    282 ; one pulse mode  

ASxxxx Assembler V02.00 + NoICE + SDCC mods  (STMicroelectronics STM8), page 29.
Hexadecimal [24-Bits]

      00815B 72 16 52 50      [ 1]  283     bset TIM1_CR1,#TIM_CR1_OPM 
                                    284 ; enable PWM output 
      00815F 72 1E 52 6D      [ 1]  285 	bset TIM1_BKR,#TIM1_BKR_MOE ; enable PWM output   
                                    286 
                           000000   287 .if 0
                                    288 0$:
                                    289 call send_pulse
                                    290 jra 0$
                                    291 .endif 
                                    292 
                                    293 ; enable ADC 
      008163 72 16 54 07      [ 1]  294     bset ADC1_TDRL,#ADC_INPUT
      008167 35 40 54 01      [ 1]  295     mov ADC1_CR1,#(4<<4) ; ADCclk=Fmaster/8 
      00816B 72 16 54 02      [ 1]  296     bset ADC1_CR2,#ADC1_CR2_ALIGN
      00816F 72 10 54 01      [ 1]  297     bset ADC1_CR1,#0 ; turn on ADC  
                                    298 
                                    299 ; signal power up 
      008173 CD 82 69         [ 4]  300     call power_on 
                                    301 
                                    302 ;-------------------------
                                    303 ; initialize detector 
                                    304 ; by reading 32 samples
                                    305 ; and compute average 
                                    306 ;--------------------------
      008176                        307 init_detector: 
      008176 4B 20            [ 1]  308     push #32
      008178 5F               [ 1]  309     clrw x 
      008179 CF 00 01         [ 2]  310     ldw SAMPLES_SUM,x  
      00817C                        311 2$: 
      00817C CD 82 13         [ 4]  312     call sample
      00817F 72 BB 00 01      [ 2]  313     addw x, SAMPLES_SUM
      008183 CF 00 01         [ 2]  314     ldw SAMPLES_SUM, x
      008186 0A 01            [ 1]  315     dec (1,sp)
      008188 26 F2            [ 1]  316     jrne 2$
      00818A 90 AE 00 20      [ 2]  317     ldw y,#32
      00818E 65               [ 2]  318     divw x,y 
      00818F CF 00 03         [ 2]  319     ldw SAMPLES_AVG,x 
                           000000   320 .if DEBUG 
                                    321     call clear_screen
                                    322     call uart_prt_int
                                    323     ld a,#13
                                    324     call uart_putc
                                    325 .endif 
      008192 84               [ 1]  326     pop a 
                                    327 
                                    328 ;-----------------
                                    329 ; detector loop 
                                    330 ;-----------------
      008193                        331 detector:
      008193 CD 82 13         [ 4]  332     call sample 
      008196 CE 00 03         [ 2]  333     ldw x,SAMPLES_AVG 
      008199 72 B0 00 0D      [ 2]  334     subw x,LAST 
      00819D CF 00 11         [ 2]  335     ldw DELTA,x 
      0081A0 2A 07            [ 1]  336     jrpl 3$
      0081A2 72 5A 00 0F      [ 1]  337     dec SLOPE 

ASxxxx Assembler V02.00 + NoICE + SDCC mods  (STMicroelectronics STM8), page 30.
Hexadecimal [24-Bits]

      0081A6 50               [ 2]  338     negw x
      0081A7 20 04            [ 2]  339     jra 4$  
      0081A9                        340 3$: 
      0081A9 72 5C 00 0F      [ 1]  341     inc SLOPE 
      0081AD                        342 4$:
      0081AD A3 00 02         [ 2]  343     cpw x,#SENSIVITY 
      0081B0 2A 06            [ 1]  344     jrpl 5$
      0081B2 72 5F 00 0F      [ 1]  345     clr SLOPE 
      0081B6 20 DB            [ 2]  346     jra detector 
      0081B8                        347 5$:      
                           000000   348 .if DEBUG 
                                    349 call uart_prt_int
                                    350 .endif 
      0081B8 CD 81 D7         [ 4]  351     call alarm 
      0081BB CD 81 C0         [ 4]  352    call adjust_avg 
      0081BE 20 D3            [ 2]  353     jra detector 
                                    354 
      0081C0                        355 adjust_avg:
                           000000   356 .if 0
                                    357     ld a,#SKIP_MAX 
                                    358     cp a,SKIP 
                                    359     jrpl 9$ 
                                    360     clr SKIP 
                                    361 .endif 
      0081C0 CE 00 01         [ 2]  362     ldw x,SAMPLES_SUM  
      0081C3 72 B0 00 03      [ 2]  363     subw x,SAMPLES_AVG 
      0081C7 72 BB 00 0D      [ 2]  364     addw x,LAST 
      0081CB CF 00 01         [ 2]  365     ldw SAMPLES_SUM,x 
      0081CE 90 AE 00 20      [ 2]  366     ldw y,#32 
      0081D2 65               [ 2]  367     divw x,y 
      0081D3 CF 00 03         [ 2]  368     ldw SAMPLES_AVG,x 
      0081D6 81               [ 4]  369 9$: ret     
                                    370 
                                    371 ;----------------------
                                    372 ; detection alarm 
                                    373 ;----------------------
      0081D7                        374 alarm:
      0081D7 72 5D 00 0F      [ 1]  375     tnz SLOPE 
      0081DB 27 35            [ 1]  376     jreq 9$
      0081DD 2B 06            [ 1]  377     jrmi 1$ 
      00015F                        378     _gled_on
      0081DF 72 17 50 0A      [ 1]    1     bres ALARM_LED_ODR,#ALARM_GLED_BIT 
      0081E3 20 04            [ 2]  379     jra 2$
      000165                        380 1$: _rled_on  
      0081E5 72 1B 50 0A      [ 1]    1     bres ALARM_LED_ODR,#ALARM_RLED_BIT 
      0081E9                        381 2$:
      0081E9 CD 82 94         [ 4]  382     call set_tone_freq 
      00016C                        383     _sound_on 
      0081EC 72 10 53 0A      [ 1]    1  	bset TIM2_CCER1,#TIM_CCER1_CC1E
      0081F0 72 10 53 00      [ 1]    2 	bset TIM2_CR1,#TIM_CR1_CEN
      0081F4 72 10 53 06      [ 1]    3 	bset TIM2_EGR,#TIM_EGR_UG
      0081F8 AE 00 0A         [ 2]  384     ldw x,#10 
      0081FB CD 82 5F         [ 4]  385     call pause 
      00017E                        386     _leds_off 
      00017E                          1     _gled_off 

ASxxxx Assembler V02.00 + NoICE + SDCC mods  (STMicroelectronics STM8), page 31.
Hexadecimal [24-Bits]

      0081FE 72 16 50 0A      [ 1]    1     bset ALARM_LED_ODR,#ALARM_GLED_BIT 
      000182                          2     _rled_off 
      008202 72 1A 50 0A      [ 1]    1     bset ALARM_LED_ODR,#ALARM_RLED_BIT 
      000186                        387     _sound_off 
      008206 72 11 53 0A      [ 1]    1 	bres TIM2_CCER1,#TIM_CCER1_CC1E
      00820A 72 11 53 00      [ 1]    2 	bres TIM2_CR1,#TIM_CR1_CEN 
      00820E 72 5F 00 0F      [ 1]  388     clr SLOPE 
      008212                        389 9$:
      008212 81               [ 4]  390     ret 
                                    391 
                                    392 ;--------------------
                                    393 ;  sample reader
                                    394 ;--------------------
      008213                        395 sample:
      008213 CD 82 44         [ 4]  396     call flush_cap 
      008216 CD 82 3A         [ 4]  397     call send_pulse 
      008219 CD 82 21         [ 4]  398     call adc_read
      00821C 72 5C 00 0B      [ 1]  399     inc SKIP   
      008220 81               [ 4]  400     ret 
                                    401 
                                    402 
                                    403 ;------------------------
                                    404 ; read ADC sample
                                    405 ; output:
                                    406 ;    X   sample 
                                    407 ;-------------------------
      008221                        408 adc_read:
      008221 35 03 54 00      [ 1]  409     mov ADC1_CSR,#ADC_INPUT 
      008225 72 10 54 01      [ 1]  410     bset ADC1_CR1,#0
      008229 72 0F 54 00 FB   [ 2]  411     btjf ADC1_CSR,#ADC1_CSR_EOC,. 
      00822E C6 54 05         [ 1]  412     ld a,ADC1_DRL 
      008231 97               [ 1]  413     ld xl,a 
      008232 C6 54 04         [ 1]  414     ld a,ADC1_DRH 
      008235 95               [ 1]  415     ld xh,a
      008236 CF 00 0D         [ 2]  416     ldw LAST,x  
      008239 81               [ 4]  417     ret 
                                    418 
                                    419 ;------------------------
                                    420 ; send short pulse 
                                    421 ; to inductor 
                                    422 ;------------------------
      00823A                        423 send_pulse:
                                    424 ;    bset TIM1_CCER2,#TIM_CCER2_CC4E 
      00823A 72 10 52 50      [ 1]  425     bset TIM1_CR1,#TIM_CR1_CEN 
      00823E 72 00 52 50 FB   [ 2]  426     btjt TIM1_CR1,#TIM_CR1_CEN,.
                                    427 ;    bres TIM1_CCER2,#TIM_CCER2_CC4E 
      008243 81               [ 4]  428     ret 
                                    429 
                                    430 ;------------------------
                                    431 ;  flush peak detector 
                                    432 ;  capacitor C19  
                                    433 ;  pin PB3 
                                    434 ;------------------------
      008244                        435 flush_cap: 
      008244 72 11 54 01      [ 1]  436     bres ADC1_CR1,#ADC1_CR1_ADON

ASxxxx Assembler V02.00 + NoICE + SDCC mods  (STMicroelectronics STM8), page 32.
Hexadecimal [24-Bits]
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

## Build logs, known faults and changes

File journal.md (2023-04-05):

### 2023-04-05

* Modifié [](bare-metal/nail-finder.v6.asm) pour réduire la persistance de l'alarme après détection.

* Complété l'assemblage final du projet.





### 2023-03-29 

* Essaie d'une nouvelle bobine monté sur une ferrite cylindrique de 12,3mm de diamètre et de 41,3mm de longueur. la bobine est enroulée avec des spires jointives sur 25mm de longueur à partir d'un millimètre de l'extrémité sensible. Le bobinage a 2 couches de fils et l'inductance mesurée est de 622uH. [spécification de la ferrite](bare-metal/ferrite-rod-4077484611.pdf)

* Modification du firmware [nail-finder.v6.asm](bare-metal/nail-finder.v6.asm).

* Modification de la schématique pour la nouvelle valeur de **L1**. 

* dernière schématique:

schématique

### 2023-03-26

* Complété assemblage du PCB circuit final. 


### 2023-03-25 

* Création d'un nouveau projet KiCAD pour le circuit choisi comme version finale du projet. [kiCAD/nail-finder/nail-finder.kicad_pro](kiCAD/nail-finder/nail-finder.kicad_pro).



* Corrigé erreur dans nail-finder.v6.asm, diviseur oublié dans la définition de la constante **ALARM_FREQ_HIGH**.

* Idée pour augmenter la sensibilité: bobinné autour d'une ferrite en forme de de **U** pour concentrer les lignes du champ magnétique entre les 2 branches du **U**. 
  Projet suspendu jusqu'à réception d'une ferrite cylindrique.

### 2023-03-24 

* Modification de [debug.asm](debug.asm) pour réception des caractères en mode interruption. Ce qui permet d'utiliser **CTRL+C** pour réinitialiser le MCU pendant les sessions de débogage.

* Test supplémentaires avec différentes bobines et largeur d'impulsion sans résultat convaincant.

### 2023-03-23

6ième version du projet. Meilleur résultat à date. 
    * plus sensible. 
    * Faux déclechements très rares.

 Nouveau programme [bare-metal/nail-finder.v6.asm](bare-metal/nail-finder.v6.asm) et nouveau circuit avec mode de fonctionnement différent. 

 

 L'inductance utilisée est bobinée avec du fil émaillé 26 AWG en spire jointives sur une barre de ferrite de 7mm de diamètre récupérée d'un vieille radio. Le bobinage débute à 7 mm de l'extérmenté et s'étant sur 3 cm, avec 2 couches de fil. La valeur d'inductance mesurée est de 821uH.    

### 2023-03-22

* Autre test avec différentes confuguration. Finalement je suis passé à un circuit résonnant parrallèle.  

### 2023-03-21

* Testé différent type d'inductance. Le meilleur résultat est obtenu avec une inductance bobiné sur une ferrite de 7mm de diamètre. 

* Modification de la schématique. 

* Écrire et tester le programme [bare-metal/s103f3-metal-pointer.asm](bare-metal/s103f3-metal-pointer.asm)

### 2023-03-19

* Création de schématique de la version 4 utilisant un MCU **STM8S103F3M**. 

* Réorganisation du [readme.md] principal.

* Ajout d'une double tonalité d'alarme pour différencier l'approche de l'éloignement. 

* Ajout du mode de détection **MODE_2** pour fin de test.

### 2023-03-17

* Modification au circuit de la version 2. 
    * Modification de la valeur du condensateur C8. Était de **100nF** remplacé par **10nF**. 
    * Suppression de la résistance de 5M1 qui était en parrallèle avec **C8**.

### 2023-03-16 

* Premier commit du dossier **bare-metal**. 

### 2023-03-09 

* Version 3 
    * Création de la feuille [bare-metal.kicad_sch](KiCAD/bare-metal.kicad_sch) dans KiCAD
    * Création du dossier **bare-metal**. Cette version est progreammée en assembleur sur **STM8S105K6B6**.

* Création de la feuille dans KiCAD pour la **version 2** qui n'utilise pas de cristal externe mais plutôt le signal **TMCO** de 8Mhz en provenance du ST-LINK. 

* Modification de [metal-detector.bas](metal-detector.bas) pour tenir compte de la dernière réversion de [STM8_TBI](https://github.com/picatout/stm8_tbi) qui ajoute les commandes **CLK_HSE** et **CLK_HSI** pour faire la commutation entre l'oscillateur  interne et l'oscillateur externe.

### 2023-03-08 

* [metal-detector.bas](metal-detector.bas) Révision 3
    * Modifié la constante  **SENSIVITY**  de **4** à **2** pour amélliorer la sensibilité. 
    * Ajout de la constante **DEBUG** et modifié le code pour n'interagir avec le terminal lorsque **DEBUG=1**
    * Sauvegarder le programme en flash 
    * Utililsé la commande **AUTORUN DETECTOR** pour exécuter le programme lors de la mise sous tension du détecteur.
    
### 2023-03-07

* Version 1 révision 2
    * Changement au circuit ainsi qu'au programme [metal-detector.bas](metal-detector.bas)

### 2023-03-03

* Mise à jour du [readme.md](readme.md)

* Création du dépot sur [https://github.com/picatout/metal-pointer](https://github.com/picatout/metal-pointer)

* Modification du circuit pour ajouter un cristal de 12Mhz pour la carte NUCLEO-S207K8

* Création du programme [clk-switch.bas](clk-switch.bas) qui permet de commuter de la carte NUCLEO 
de l'oscillateur interne **HSI** au cristal 12Mhz **HSE**. 

* Mise à jour du programme [metal-detector.bas](metal-detector.bas) pour fonctionner avec le cristal 
externe au lieu de l'oscillateur interne.

* Mise à jour du fichier []()

### 2023-03-02

* Ajout du programme [tunig.bas](tuning.bas)

### 2023-03-01

* Remplacement de stm8_eforth par stm8_tbi sur la carte NUCLEO-S207K8

* Création du fichier [metal-detector.bas](metal-detector.bas)

### 2023-02-20

* Création du projet 

* Installation de stm8_eforth sur la carte NUCLEO-S207K8

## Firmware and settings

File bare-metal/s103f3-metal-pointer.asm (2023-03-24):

;--------------------
; bare metal version 
; on STM8S103f3m 
;--------------------

    .module METAL_POINTER 

    .include "inc/macros.inc" 
    .include "inc/stm8s103f3.inc"

    .page 

; defined for debug.asm 
DEBUG=0
FMSTR=12000000 ; 

MODE_1=1

.if MODE_1 
MODE_2=0 
.else 
MODE_2=1
.endif 

;;;;;;;;;;;;;;;;;;;;;;;;;;;;;;;;;;;;;;;
; peripherals usage 
;  TIMER4 1 msec timer, use interrupt 
;  TIMER1 CH4  PWM, PC4 pin 14
;  TIMER2 CH1  alarm sound, PD4 pin 1
;  alarm GREEN LED, PC3 pin 13
;  alarm RED LED, PC5 pin 15
;  ADC read AIN3, PD2 pin 19
;;;;;;;;;;;;;;;;;;;;;;;;;;;;;;;;;;;;;;;

;------------------------------
;  system constants 
;------------------------------
ALARM_RLED_BIT = 5 ; RED LED PC5
ALARM_GLED_BIT = 3 ; GREEN LED PC3
ALARM_LED_ODR = PC_ODR 
ALARM_LED_DDR = PC_DDR 
ALARM_LED_CR1 = PC_CR1 
ALARM_SOUND = 4 ; PD4 
ALARM_FREQ_HIGH=FMSTR; 12Mhz/1000 
ALARM_FREQ_LOW=FMSTR/700; 12Mhz/700
ADC_INPUT = 3
ADC_ODR = PD_ODR
ADC_DDR = PD_DDR 
ADC_BIT = 2 
;; detector sensivity
;; increment to reduce false detection 
SENSIVITY = 2

; FREQ_LC=75702 ; L=442Uh, C=10nF 
; FREQ_LC= 63867 ; L=621uH, c=10nF 
; FREQ_LC=55177  ; L=832uH, C=10nF 
FREQ_LC=50329 ; L=1mH, C=10nF 

;; period value for TIMER1 frequency 
;; period = 12e6/FREQ_LC - 1
TMR1_PERIOD=12000000/FREQ_LC-1 
; duty cycle 50%
TMR1_DC= (TMR1_PERIOD/2)

    ; turn on green LED 
    .macro _gled_on 
    bres ALARM_LED_ODR,#ALARM_GLED_BIT 
    .endm 

    ; turn off green LED 
    .macro _gled_off 
    bset ALARM_LED_ODR,#ALARM_GLED_BIT 
    .endm 

    ; turn on red LED 
    .macro _rled_on 
    bres ALARM_LED_ODR,#ALARM_RLED_BIT 
    .endm 

    ; turn off red LED 
    .macro _rled_off 
    bset ALARM_LED_ODR,#ALARM_RLED_BIT 
    .endm 

    ; turn on both LED 
    .macro _leds_on 
    _gled_on 
    _rled_on 
    .endm 

    ; turn of both LED 
    .macro _leds_off 
    _gled_off 
    _rled_off 
    .endm 

    .macro _sound_on     
 	bset TIM2_CCER1,#TIM_CCER1_CC1E
	bset TIM2_CR1,#TIM_CR1_CEN
	bset TIM2_EGR,#TIM_EGR_UG
    .endm 

    .macro _sound_off 
	bres TIM2_CCER1,#TIM_CCER1_CC1E
	bres TIM2_CR1,#TIM_CR1_CEN 
    .endm 

;**********************************************************
        .area DATA (ABS)
        .org RAM_BASE 
;**********************************************************
ALARM_DLY: .blkb 1 ; control alarm duration 
SAMPLES_SUM: .blkw 1   ; sum of ADC reading  
SAMPLES_AVG: .blkw 1  ; mean of 32 reading  
CNTDWN: .blkw 1 ; count down timer 
PERIOD: .blkw 1 ; PWM period count 
CHANGE: .blkb 1 ; 1=up|-1=down|0=same 
COUNT: .blkb 1 ; count changes in same direction 
LAST:  .blkw 1 ; last sample value 
DELTA: .blkb 1 ; 128*(average-last) 

;**********************************************************
        .area SSEG (ABS) ; STACK
        .org 0x1700
        .ds 256 
; space for DATSTK,TIB and STACK         
;**********************************************************

;**********************************************************
        .area HOME ; vectors table
;**********************************************************
	int cold_start	        ; reset
	int NonHandledInterrupt	; trap
	int NonHandledInterrupt	; irq0
	int NonHandledInterrupt	; irq1
	int NonHandledInterrupt	; irq2
	int NonHandledInterrupt	; irq3
	int NonHandledInterrupt	; irq4
	int NonHandledInterrupt	; irq5
	int NonHandledInterrupt	; irq6
	int NonHandledInterrupt	; irq7
	int NonHandledInterrupt	; irq8
	int NonHandledInterrupt	; irq9
	int NonHandledInterrupt	; irq10
	int NonHandledInterrupt	; irq11
	int NonHandledInterrupt	; irq12
	int NonHandledInterrupt	; irq13
	int NonHandledInterrupt	; irq14
	int NonHandledInterrupt	; irq15
	int NonHandledInterrupt	; irq16
	int NonHandledInterrupt	; irq17
	int NonHandledInterrupt	; irq18
	int NonHandledInterrupt	; irq19
	int NonHandledInterrupt	; irq20
	int NonHandledInterrupt	; irq21
	int NonHandledInterrupt	; irq22
	int Timer4Handler	    ; irq23
	int NonHandledInterrupt	; irq24
	int NonHandledInterrupt	; irq25
	int NonHandledInterrupt	; irq26
	int NonHandledInterrupt	; irq27
	int NonHandledInterrupt	; irq28
	int NonHandledInterrupt	; irq29

;**********************************************************
        .area CODE
;**********************************************************

; non handled interrupt reset MCU
NonHandledInterrupt:
        iret 
        ld a, #0x80
        ld WWDG_CR,a ; WWDG_CR used to reset mcu

; used for count down timer 
Timer4Handler:
	clr TIM4_SR
.if MODE_2 
    tnz ALARM_DLY
    jreq 0$ 
    dec ALARM_DLY
    jrne 0$
    _leds_off 
    _sound_off
0$:  
.endif    
    ldw x,CNTDWN 
    jreq 1$
    decw x 
    ldw CNTDWN,x
1$:         
    iret 


; entry point at power up 
; or reset 
cold_start: 
; initialize clock to HSE
; no divisor 12 Mhz crystal  
clock_init:
    sim ; disable interrupts 
    clr CLK_CKDIVR
    bres CLK_SWCR,#CLK_SWCR_SWIF 
    mov CLK_SWR,#CLK_SWR_HSE ; 12 Mhz crystal
    btjf CLK_SWCR,#CLK_SWCR_SWIF,. 
	bset CLK_SWCR,#CLK_SWCR_SWEN
; initialize stack pointer 
stack_init: 
    ldw x,#RAM_SIZE-1 
    ldw sp,x 
; clear all ram 
1$: clr (x)
    decw x 
    jrne 1$        
; disable all unused peripheral clock
    ld a,#0xB0 ; enable timers 1,2,4 
    ld CLK_PCKENR1,a 
    ld a,#(1<<3) ; ADC1 
    ld CLK_PCKENR2,a 
; activate pull up on all unused inputs 
; to reduce noise 
	ld a,#255 
	ld PA_CR1,a  
 	ld PB_CR1,a
	ld PE_CR1,a 
	ld PF_CR1,a 
    ld a,#(1<<6)|(1<<7)   
    ld PC_CR1,a  
    ld a,#(1<<1)|(1<<3)|(1<<5)|(1<<6)
	ld PD_CR1,a    

; set PC4 as output high 
; this is TIM1_CH4 output 
; want it low when PWM is off     
    bset PC_DDR,#4 ; output mode 
    bset PC_ODR,#4 ; low 
; set alarm LED as output 
    bres ALARM_LED_CR1,#ALARM_GLED_BIT ; open drain 
    bset ALARM_LED_DDR,#ALARM_GLED_BIT
    bres ALARM_LED_CR1,#ALARM_RLED_BIT
    bset ALARM_LED_DDR,#ALARM_RLED_BIT  
    _leds_off     

.if DEBUG 
    call uart_init 
.endif     
; initialize timer4, used for millisecond interrupt  
timer4_init: 
	bres TIM4_CR1,#TIM4_CR1_CEN 
	mov TIM4_PSCR,#6 ; prescale 64  
	mov TIM4_ARR,#187 ; for 1msec. 12Mhz/64/1000 
	bset TIM4_IER,#TIM4_IER_UIE 
	bset TIM4_CR1,#TIM4_CR1_CEN
    bset TIM4_EGR,#TIM4_EGR_UG 
    rim

; initialize TIMER2 for 1Khz tone generator 
timer2_init:
    bres PD_CR1,#4 ; open drain output 
 	mov TIM2_CCMR1,#(6<<TIMx_CCRM1_OC1M) ; PWM mode 1 
	mov TIM2_PSCR,#0 ; 
    mov TIM2_ARRH,#ALARM_FREQ_LOW>>8  
    mov TIM2_ARRL,#ALARM_FREQ_LOW&255 
    mov TIM2_CCR1H,#(ALARM_FREQ_LOW/2)>>8
    mov TIM2_CCR1L,#(ALARM_FREQ_LOW/2)&255 
    _sound_off
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

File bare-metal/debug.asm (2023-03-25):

;------------------------
; debug support 
; using UART 
; to use it define:
; DEBUG=1
; FMSTR= frequency in Hertz  
; in main project file
;-----------------------

    .module UART_DEBUG 
    .include "inc/ascii.inc" 

.if DEBUG 

;-----------------------------
; define these constants 
; according to selected UART 
;-----------------------------
STM8S105=0 
STM8S103=1

.if STM8S105 
UART_BRR1=UART2_BRR1 
UART_BRR2=UART2_BRR2 
UART_DR=UART2_DR 
UART_SR=UART2_SR 
UART_CR1=UART2_CR1
UART_CR2=UART2_CR2 
UART_CLK_PCKENR=CLK_PCKENR1 
UART_CLK_PCKENR_UART=CLK_PCKENR1_UART2 
.else ; STM8S103  
UART_BRR1=UART1_BRR1 
UART_BRR2=UART1_BRR2 
UART_DR=UART1_DR 
UART_SR=UART1_SR 
UART_CR1=UART1_CR1
UART_CR2=UART1_CR2 
UART_CLK_PCKENR=CLK_PCKENR1 
UART_CLK_PCKENR_UART=CLK_PCKENR1_UART1 
.endif 

;----------------------
; UART receive handler 
;----------------------
uart_rx_handler:
    clr RX_CHAR 
    btjf UART_SR,#UART_SR_RXNE,9$ 
    ld a,UART_DR
    ld RX_CHAR, a
    call uart_putc   
    cp a,#CTRL_C 
    jrne 9$ 
    jp sofware_reset
9$:
    iret 

;------------------
; initialize UART 
; 115200 BAUD 
; 8N1 
;------------------
uart_init::
; enable UART clock
	bset UART_CLK_PCKENR,#UART_CLK_PCKENR_UART 	
uart_set_baud:: 
	push a 
	bres UART_CR1,#UART_CR1_PIEN
; baud rate 115200 : Fmaster/115200
	ldw x,#FMSTR/115200
    ld a,#16 
    div x,a 
    ld (1,sp),a 
    ld a,xh 
    add a,(1,sp)
    ld UART_BRR2,a ; must be loaded first
	ld a,xl 
    ld UART_BRR1,a 
    clr UART_DR
	mov UART_CR2,#((1<<UART_CR2_TEN)|(1<<UART_CR2_REN)|(1<<UART_CR2_RIEN))
;	bset UART_CR2,#UART_CR2_SBK
;    btjf UART_SR,#UART_SR_TC,.
	pop a 
	ret

;--------------------
; send a character 
; input:
;   A   character to send
;---------------------------
uart_putc:: 
    btjf UART_SR,#UART_SR_TXE,.
    ld UART_DR,a 
    ret 

;--------------------------
; receive a character 
; output:
;   A    0| char 
uart_getc::
    ld a,RX_CHAR 
    ret 

;------------------
; wait for a character 
; from UART 
; output:
;    A   char 
;--------------------
uart_wait_char:
    call uart_getc 
    tnz a 
    jreq uart_wait_char  
    ret

;-------------------------
; send ASCIZ string 
; input:
;    X    *string 
;-------------------------
uart_puts:: 
    ld a,(x)
    jreq 9$
    call uart_putc 
    incw x 
    jra uart_puts 
9$: btjf UART_SR,#UART_SR_TC,9$    
    ret 

;---------------
; print integer 
; input:
;   X   integer 
;---------------
uart_prt_int:
    push a
    pushw y 
    clrw y 
1$:
    cpw x,#0
    jreq 4$ 
    ld a,#10
    div x,a 
    add a,#'0 
    push a 
    incw y 
    jra 1$ 
4$: tnzw y 
    jreq 7$
6$: pop a 
    call uart_putc 
    decw y 
    jrne 6$
    jra 8$ 
7$: ld a,#'0
    call uart_putc 
8$:
    ld a,#32 
    call uart_putc 
    btjf UART_SR,#UART_SR_TC,.
    popw y 
    pop a 
    ret 

;------------------------
; clear terminal screen 
;-------------------------
clear_screen:
    ld a,#27 
    call uart_putc 
    ld a,#'c 
    call uart_putc 
    ret 
    
.endif ; DEBUG 

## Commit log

2023-02-20 pin point metal detector first commit
    [pin-point-metal-detector.kicad_pcb, pin-point-metal-detector.kicad_sch]
2023-03-02 first version
    [pin-point-metal-detector.kicad_sch]
2023-03-03 ajout de tuning.bas
2023-03-03 Modification du circuit pour ajouter un cristal externe de 12Mhz
2023-03-03 Ajout du journal et mise à jour du readme.md
    [pin-point-metal-detector.kicad_sch]
2023-03-08 version 1 révison 2
    [pin-point-metal-detector.kicad_sch]
2023-03-08 Modification au circuit
    [pin-point-metal-detector.kicad_sch]
2023-03-09 version 2
    [version-2.kicad_sch]
2023-03-09 récupération de readme.md effacé par erreur
2023-03-16 premier commit sur bare-metal
    [pin-point-metal-detector.kicad_sch, version-2.kicad_sch]
2023-03-17 ajout de clear_screen dans debug.asm
2023-03-17 modification à la version 2 et à metal-detector.bas
    [pin-point-metal-detector.kicad_sch, version-2.kicad_sch]
2023-03-19 Ajout du mode 2 pour test
    [pin-point-metal-detector.kicad_sch]
2023-03-19 Ajout du mode 2 pour test ainsi que d'une double tonalité
2023-03-19 bare-metal:Ajout du mode 2 pour test ainsi que d'une double tonalité Modification du circuit pour ajouter un transistor buffer au circuit du haut-parleur
2023-03-20 Création de la schématique de la version 4 utilisant un STM8S103M
    [pin-point-metal-detector.kicad_sch]
2023-03-22 written s103f3-bare-metal.asm tested different coils. Best result with ferrite rod wounded coil.
    [pin-point-metal-detector.kicad_sch]
2023-03-22 Updated schematic version 4 on s103f3m
2023-03-22 modification du circuit sur STM8103F3M
    [pin-point-metal-detector.kicad_sch]
2023-03-22 update readme.md for last tested circuit
2023-03-24 New design and new software in bare-metal. Best result up to now
    [pin-point-metal-detector.kicad_sch]
2023-03-24 added new circuit in KiCAD to git
    [bare-metal.kicad_sch, nail-detector.v5.kicad_sch, stm8s103f3-version.kicad_sch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]
2023-03-25 correction mineure dans nail-finder.asm
    [nail-finder.v6.asm]
2023-03-25 circuit final choisi nail-finder.v7.png
    [bare-metal.kicad_sch, nail-finder.kicad_pcb, nail-finder.kicad_sch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]
2023-03-25 corretion to final schematic
    [nail-finder.kicad_sch]
2023-03-26 added assembly image
2023-03-26 pcb final assembly completed
2023-03-30 New coil tested, firmware update sensivity improved
    [nail-finder.kicad_sch]
2023-04-05 assemlage final
    [nail-finder.kicad_sch]
2023-04-05 modifié nail-finder.asm pour réduire la persistance de l'alarme après détection
2023-04-28 mise à jour de metal-detector.bas pour la version V4.0R1 de tinyBASIC
2023-04-28 correction à meta-detector.bas pour fonctionner avec la version V4.0R1 de stm8 Tiny BASIC
    [metal-detector.bas]
